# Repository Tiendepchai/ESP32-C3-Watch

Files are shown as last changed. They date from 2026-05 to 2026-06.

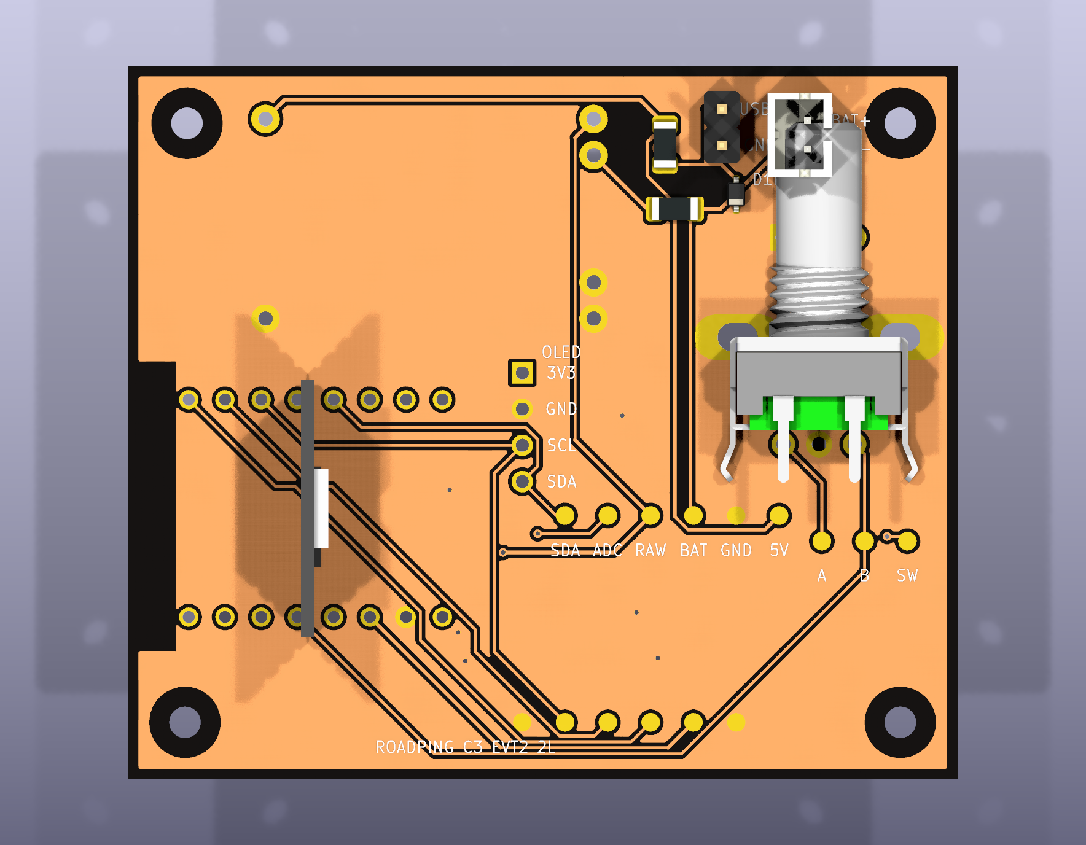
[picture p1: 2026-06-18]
hardware/kicad/roadping-c3-compact-evt-v2/analysis/baseline-top.png

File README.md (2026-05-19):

# ESP32-C3 ANCS Watch






**ESP32-C3 ANCS Watch** is an ESP-IDF firmware project for a compact BLE watch-style accessory.  
It pairs with an iPhone, subscribes to Apple Notification Center Service (ANCS), fetches notification attributes, synchronizes time, and renders notifications on a 128 × 64 SH1106 OLED display.

> **Project status:** Active firmware prototype. The core BLE/ANCS/display flow is implemented; power monitoring and iOS companion features are optional or under development.

---

## Table of Contents

- [Overview](#overview)
- [Key Features](#key-features)
- [System Architecture](#system-architecture)
- [Hardware](#hardware)
- [Firmware Layout](#firmware-layout)
- [Notification Ordering](#notification-ordering)
- [Getting Started](#getting-started)
- [Build and Flash](#build-and-flash)
- [Usage](#usage)
- [Testing Checklist](#testing-checklist)
- [Troubleshooting](#troubleshooting)
- [Roadmap](#roadmap)
- [License](#license)

---

## Overview

The firmware implements the standard ANCS accessory flow:

1. The ESP32-C3 advertises as a BLE peripheral.
2. The iPhone connects and creates a secure BLE bond.
3. After encryption is enabled, the ESP32-C3 switches role logically to a GATT client and discovers ANCS on the iPhone.
4. The ESP32-C3 subscribes to the ANCS Notification Source and Data Source characteristics.
5. For each notification UID, the firmware requests:
   - `AppIdentifier`
   - `Title`
   - `Message`
   - `Date`
6. Notifications are stored locally and sorted with the newest notification first.
7. The display manager renders connection status, watchface, notification detail, and navigation views.

---

## Key Features

- BLE pairing and bonding powered by NimBLE.
- Bonded reconnect flow using directed advertising first, then general advertising fallback.
- ANCS discovery, CCCD subscription, notification event handling, and attribute parsing.
- Date-based notification ordering using ANCS `Date` when available.
- Temporary local receive timestamp while waiting for notification attributes.
- iOS Current Time Service client for watchface time synchronization.
- SH1106 128 × 64 OLED rendering for:
  - connection status
  - watchface
  - notification list/detail
  - navigation state
- In-memory notification store with configurable filtering.
- NVS-backed settings and bond state persistence.
- Two-button physical control for:
  - notification navigation
  - clearing notifications
  - changing filters
  - resetting bond state
- Optional SwiftUI companion scaffold for future configuration and navigation handoff.

---

## System Architecture

```text
┌────────────────────┐
│      iPhone        │
│  ANCS + CTS Server │
└─────────┬──────────┘
          │ BLE encrypted link
          ▼
┌──────────────────────────────────────┐
│              ESP32-C3                │
│                                      │
│  ┌───────────────┐   ┌────────────┐  │
│  │ BLE Manager   │──▶│ ANCS Client│  │
│  └───────┬───────┘   └─────┬──────┘  │
│          │                 │         │
│          ▼                 ▼         │
│  ┌───────────────┐   ┌─────────────┐ │
│  │ CTS Client    │   │ Notification│ │
│  │ Time Sync     │   │ Store       │ │
│  └───────┬───────┘   └─────┬───────┘ │
│          │                 │         │
│          ▼                 ▼         │
│  ┌────────────────────────────────┐  │
│  │        Display Manager         │  │
│  │      SH1106 OLED Rendering     │  │
│  └────────────────────────────────┘  │
│                                      │
│  ┌────────────────────────────────┐  │
│  │        Storage Manager         │  │
│  │        NVS Settings/Bonds      │  │
│  └────────────────────────────────┘  │
└──────────────────────────────────────┘
```

---

## Hardware

| Component | Specification |
| --- | --- |
| MCU | ESP32-C3 |
| Display | SH1106 128 × 64 OLED |
| Display bus | I2C |
| Button A | GPIO3, active low |
| Button B | GPIO4, active low |

### Default Wiring

| Function | ESP32-C3 Pin |
| --- | --- |
| OLED VCC | 3V3 |
| OLED GND | GND |
| OLED SDA | GPIO6 |
| OLED SCL | GPIO7 |
| Button A | GPIO3 to GND |
| Button B | GPIO4 to GND |

Board-level constants are defined in:

```text
components/board_config/include/board_config.h
```

---

## Firmware Layout

| Path | Purpose |
| --- | --- |
| `main/` | Application state machine, UI flow, and event orchestration |
| `components/ble_manager/` | NimBLE initialization, advertising, bonding, reconnect, and config GATT service |
| `components/ancs_client/` | ANCS discovery, notification subscription, attribute request, and response parser |
| `components/cts_client/` | iOS Current Time Service client |
| `components/display_manager/` | SH1106 driver, framebuffer, watchface rendering, and notification rendering |
| `components/notification_store/` | In-memory notification storage, filtering, and sorting |
| `components/storage_manager/` | NVS-backed settings and persistent state |
| `components/power_manager/` | Optional battery and power monitoring |
| `ios/ANCSWatchConfig/` | Optional SwiftUI companion app scaffold |

---

## Notification Ordering

The notification ordering pipeline is designed to avoid relying only on local receive time.

```text
ANCS Notification Source event
        │
        ▼
Extract NotificationUID
        │
        ▼
Request attributes:
AppIdentifier, Title, Message, Date
        │
        ▼
Parse ANCS Data Source response
        │
        ▼
Use ANCS Date if available
        │
        ▼
Update notification record
        │
        ▼
Sort newest first
```

When a notification event first arrives, the firmware stores it with the local receive timestamp as a temporary value.  
After the ANCS `Date` attribute is fetched, the stored record is updated and the notification list is re-sorted by timestamp in descending order.

This allows notifications such as:

```text
Messenger  - 1 second ago
MoMo       - 2 minutes ago
```

to appear in the expected order, with the newest notification at the top.

---

## Getting Started

### Prerequisites

Install and configure:

- ESP-IDF v6.0 or newer
- Python environment required by ESP-IDF
- USB serial driver for your ESP32-C3 board
- An iPhone with Bluetooth enabled
- Optional: nRF Connect for BLE debugging

### Clone the Repository

```bash
git clone <your-repository-url>
cd esp32-c3-ancs-watch
```

### Set the ESP-IDF Target

```bash
idf.py set-target esp32c3
```

---

## Build and Flash

### Activate ESP-IDF

Use the activation script generated by your ESP-IDF installation.

Example:

```bash
source "$HOME/.espressif/tools/activate_idf_v6.0.sh"
```

Alternatively, if ESP-IDF is installed globally:

```bash
. "$IDF_PATH/export.sh"
```

### Build

```bash
idf.py build
```

### Flash

Replace the port with the serial device used by your board.

```bash
idf.py -p /dev/cu.usbmodemXXXX flash
```

### Monitor Logs

```bash
idf.py -p /dev/cu.usbmodemXXXX monitor
```

### Flash and Monitor in One Command

```bash
idf.py -p /dev/cu.usbmodemXXXX flash monitor
```

---

## Usage

### First Pairing

1. Flash the firmware to the ESP32-C3.
2. Open the Bluetooth settings on iOS.
3. Select the ESP32-C3 accessory.
4. Accept the pairing request.
5. Wait until the BLE link is encrypted and ANCS discovery completes.
6. Send a test notification to the iPhone.
7. Verify that the OLED displays the notification.

### Reconnect Flow

After a successful bond, the firmware tries:

1. Directed advertising to the bonded iPhone.
2. General advertising fallback if directed reconnect fails.
3. ANCS rediscovery after the encrypted link is restored.

### Button Controls

| Action | Expected Behavior |
| --- | --- |
| Button A | Navigate through notifications or UI views |
| Button B | Change filter, clear notification, or trigger secondary action |
| Long press / configured combo | Reset bond state or enter maintenance flow |

> Exact button behavior depends on the current firmware state machine and board configuration.

---

## Testing Checklist

Before testing a first-pair flow:

- Clear the iOS Bluetooth bond for the ESP32-C3.
- Clear stored bonds on the ESP32-C3.
- Reboot both devices if bonding behavior is inconsistent.

Recommended validation sequence:

- Pair from iOS or nRF Connect.
- Confirm the first bond is retained locally.
- Check logs for:

```text
bond store peers after secure=1
```

- Wait for:

```text
ANCS ready, attrs=enabled
```

- Send several notifications from different apps.
- Verify that notification details are fetched correctly.
- Verify that notifications are sorted by ANCS `Date`.
- Walk out of range to force a disconnect.
- Return to range and confirm bonded reconnect works.
- Confirm pre-existing or pending notifications can wake the display and render correctly.
- Test button navigation, filter changes, clear action, and bond reset.

---

## Troubleshooting

### ANCS does not become ready

Check that:

- The iPhone accepted the BLE pairing request.
- The connection is encrypted.
- The ESP32-C3 bond was not erased after pairing.
- ANCS discovery runs only after encryption.
- Notification permissions are enabled on iOS.

Useful log marker:

```text
ANCS ready, attrs=enabled
```

### Notifications appear but details are missing

Check that:

- Data Source subscription succeeded.
- Control Point writes are accepted.
- `GetNotificationAttributes` is sent with the correct `NotificationUID`.
- The parser handles fragmented Data Source responses.

### Notification order is incorrect

Check that:

- `Date` is included in the requested ANCS attributes.
- The firmware updates the temporary receive timestamp after `Date` arrives.
- The notification store re-sorts the list after attribute parsing.

### Reconnect does not work

Check that:

- Bond data is stored in NVS.
- Directed advertising uses the bonded peer address.
- General advertising fallback starts after directed advertising fails.
- iOS still has the accessory saved in Bluetooth settings.

### macOS ESP-IDF `platform.mac_ver()` issue

If the local Python environment fails because of a macOS version parsing issue, use a clean ESP-IDF Python environment first.  
If the issue persists, the following development workaround can be used:

```bash
IDF_COMPONENT_MANAGER=0 python -c 'import os, platform, runpy, sys; tools=os.path.join(os.environ["IDF_PATH"],"tools"); sys.path.insert(0,tools); platform.mac_ver=lambda release="", versioninfo=("", "", ""), machine="": ("26.1", ("", "", ""), os.uname().machine); sys.argv=[os.path.join(tools,"idf.py")]+sys.argv[1:]; runpy.run_path(sys.argv[0], run_name="__main__")' build
```

---

## Roadmap

- [ ] Add battery percentage monitoring.
- [ ] Add charging status display.
- [ ] Improve notification grouping by app.
- [ ] Add persistent notification history if required.
- [ ] Finalize iOS SwiftUI companion app.
- [ ] Add configurable button actions.
- [ ] Add screenshots or hardware photos.
- [ ] Add CI build workflow for ESP-IDF.
- [ ] Add release binaries and flashing instructions.

---

## License

This project is licensed under the MIT License. See [LICENSE](LICENSE) for details.

---

## Vietnamese Summary

**ESP32-C3 ANCS Watch** là firmware ESP-IDF cho thiết bị đeo nhỏ dùng BLE. Thiết bị ghép đôi với iPhone, subscribe Apple Notification Center Service, lấy thông tin `AppIdentifier`, `Title`, `Message`, `Date`, sau đó hiển thị thông báo lên OLED SH1106 128 × 64.

Điểm chính:

- Pairing/bonding BLE bằng NimBLE.
- Tự reconnect với iPhone đã bond.
- Fetch chi tiết thông báo qua ANCS.
- Sort thông báo theo `Date` để thông báo mới nhất hiện trên đầu.
- Đồng bộ giờ qua iOS Current Time Service.
- Hiển thị watchface và notification bằng SH1106 OLED.
- Lưu cấu hình bằng NVS.
- Điều khiển bằng hai nút vật lý.

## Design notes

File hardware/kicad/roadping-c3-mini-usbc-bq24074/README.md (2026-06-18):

# RoadPing C3 Mini - USB-C + BQ24074

Production-oriented KiCad design for a compact ESP32-C3 board.

## Key Components

- **ESP32-C3-MINI-1-N4** — RISC-V Wi-Fi/BLE SoC module
- **BQ24074** — Linear battery charger with power-path management
- **Single USB-C port** — Charge battery + flash firmware
- **SH1106 OLED** — Connected via I2C on GPIO 0/1 (or alternative)

## Design Directives

- Power path: USB-C 5V -> BQ24074 -> 3.3V LDO -> ESP32-C3 + peripherals
- LiPo/Li-ion battery management with NTC thermistor monitoring
- Single USB-C for both charging and UART/JTAG flashing
- Compact form factor (< 50 x 25 mm)

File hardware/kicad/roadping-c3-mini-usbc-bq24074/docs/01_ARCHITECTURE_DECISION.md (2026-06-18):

# Architecture Decision Record: RoadPing C3 Mini

**Date:** 2026-06-16
**Board:** RoadPing C3 Mini (roadping-c3-mini-usbc-bq24074)
**Status:** DRAFT (pre-schematic)

---

## 1. Overview

RoadPing C3 Mini is a compact iOS ANCS notification display with SH1106 OLED, PEC11R encoder, and LiPo battery power. This document records the five highest-impact architecture decisions.

### Design Goals (ranked)
- P0: Single USB-C port for charge + flash/debug
- P0: Charge-and-run (power-path) on 1S LiPo
- P0: Native USB-SERIAL-JTAG (no external UART bridge)
- P1: Board area < 4000 mm² (80×50 mm target)
- P1: BLE ANCS push notification display
- P2: Battery voltage monitoring

## 2. Decision 1: MCU Selection — ESP32-C3-MINI-1-N4

| Parameter | ESP32-C3-MINI-1-N4 | ESP32-S3-MINI-1-N8 | ESP32-PICO-V3-ZERO |
|---|---|---|---|
| Core | Single RISC-V 160 MHz | Dual Xtensa LX7 240 MHz | Dual Xtensa LX6 240 MHz |
| Native USB | USB-SERIAL-JTAG | USB OTG | USB OTG |
| BLE | BLE 5.0 | BLE 5.0 | Classic BT + BLE 4.2 |
| Flash/PSRAM | 4MB / none | 8MB / 2MB | 4MB / 2MB |
| Module area | 18.0×22.5 mm | 18.0×25.5 mm | 21.0×21.0 mm |
| GPIO available | 14 | 26 | 27 |
| Price (1k) | ~$2.50-3.00 | ~$3.50-4.50 | ~$4.00-5.00 |

**Rationale:** Native USB-SERIAL-JTAG eliminates external UART bridge. Sufficient compute for ANCS + display. Smallest footprint. Adequate GPIO count (12 used of 14). Lower power than S3/PICO.

## 3. Decision 2: Power-Path Charger — BQ24074RGTR

Replaces TP4056 module. True power-path management (DPPM):
- USB present → system powered from USB, battery charged
- USB removed → seamless switch to battery (<20µs)
- No discrete ORing diodes or P-MOSFET required

| Feature | TP4056 (EVT) | BQ24074 (This design) |
|---|---|---|
| Power path | None | True DPPM |
| Package | THT module | WQFN-20 (3.5×3.5 mm) |
| PCB area | ~600 mm² | ~60 mm² |
| Charge current | 1A (R_PROG) | 1.5A max (ISET) |
| Status outputs | Single CHG LED | CHG + FAULT open-drain |
| NTC monitoring | None | TS pin (JEITA) |
| Safety timer | None | 5h default |

**ISET=1.1kΩ → ~910mA charge, ILIM=10kΩ → ~500mA input limit. TS fixed 10k+10k divider (no NTC).**

### Power Tree
```
USB-C VBUS (5V) → PTC F1 (1206L110SLWR) → TVS D1 (PESD5V0S1BA)
  → BQ24074 IN → BQ24074 OUT (SYS_RAW) → AP2112K-3.3 → 3V3 rail
               → BQ24074 BAT → JST-PH LiPo
```

## 4. Decision 3: USB-C Input — TYPE-C-31-M-12

Native USB-C receptacle with CC 5.1kΩ pulldowns (sink). USBLC6-2SC6 ESD on D+/D-.

```
USB-C D+ → USBLC6-2SC6 → opt 27Ω R → GPIO19 (USB_D+)
USB-C D- → USBLC6-2SC6 → opt 27Ω R → GPIO18 (USB_D-)
```

## 5. Decision 4: Gated Battery ADC (BSS138)

470k+470k divider gated by BSS138 N-FET. Gate HIGH → divider enabled, ADC reads VBAT×0.5. Gate LOW → <1µA leakage. GPIO1 gate control.

**Phase plan:** Phase 1 = gated ADC, Phase 2 = MAX17048 fuel gauge (future).

## 6. Decision 5: 4-Layer Stackup

F.Cu / In1.Cu (GND plane) / In2.Cu (PWR) / B.Cu. 1.6mm, ENIG. USB D+/D- 90Ω differential on F.Cu ref In1.Cu.

## 7. GPIO Allocation

| GPIO | Function | GPIO | Function |
|---|---|---|---|
| 0 | BAT_ADC (ADC1_CH0) | 6 | BQ24074_CHG (input) |
| 1 | GPIO_EN_ADC (BSS138 gate) | 7 | BQ24074_FAULT (input) |
| 2 | ENC_A | 8 | I2C_SDA |
| 3 | ENC_B | 9 | BOOT (unconnected) |
| 4 | ENC_SW | 10 | I2C_SCL |
| 5 | BQ24074_CE (output) | 18 | USB_D- | 19 | USB_D+ | 20 | UART_RX | 21 | UART_TX |

Total: 15 GPIOs used.

## 8. Schematic Fragments

### USB-C Input
```
J1: A1/A12/B1/B12=GND, A4/A9/B4/B9=VBUS, A5=CC1→5.1k→GND, B5=CC2→5.1k→GND
A6/B6=D+→USBLC6→GPIO19, A7/B7=D-→USBLC6→GPIO18
Shield: 1MΩ + 0.1µF to GND
```

### BQ24074
```
U1: IN(1,2)=VBUS, OUT(8)=SYS_RAW, BAT(12,13)=BAT_CONN+
ISET(4)=1.1k→GND, ILIM(5)=10k→GND, TS(6)=10k→OUT + 10k→GND
/CE(7)=GPIO5↑10k, CHG(10)=GPIO6↑10k, FAULT(11)=GPIO7↑10k
```

### AP2112K
```
U2: VIN(1)=SYS_RAW, EN(3)=SYS_RAW, VOUT(5)=3V3
```

### Gated ADC
```
Q1(BSS138): GATE=GPIO1+100k→GND, DRAIN=divider jct, SOURCE=GND
R_TOP=470k VBAT→divider, R_BOTTOM=470k divider→Q1 drain
C_FILTER=100n divider→GND, divider→GPIO0
```

### SH1106
```
DS1: VDD=3V3, GND=GND, SCK=GPIO10, SDA=GPIO8
Pull-ups: 4.7k DNP
```

### PEC11R
```
S1: A=GPIO2↑10k, C=GND, B=GPIO3↑10k
SW: 1=GPIO4↑10k, 2=GND
Debounce: 10n DNP
```

### UART Debug
```
TP_TX=GPIO21, TP_RX=GPIO20, TP_GND=GND, TP_3V3=3V3
Pads: 1.3mm round, ENIG, 2.54mm pitch
```

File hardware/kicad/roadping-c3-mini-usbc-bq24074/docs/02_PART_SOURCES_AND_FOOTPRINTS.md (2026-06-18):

# Part Sources and Footprints

| Part Name | Manufacturer | Package | Datasheet Source | Symbol Source | Footprint Source | Risk | Decision | Notes |
|---|---|---|---|---|---|---|---|---|
| ESP32-C3-MINI-1-N4 | Espressif | 42-pin castellated SMD module, 15.5 x 20.0 mm, 2.0 mm pitch | <https://www.espressif.com/sites/default/files/documentation/ESP32-C3-MINI-1_Datasheet_EN.pdf> | Custom `roadping-c3:ESP32-C3_SUPERMINI_TH` (via project sym lib) **but this is a different part** — SuperMini_TH dev board, not MINI-1-N4 | Custom `roadping-c3:MODULE_ESP32-C3_SUPERMINI_TH` (via project footprint lib) **same mismatch** | MEDIUM | NEED_REVIEW | PART MISMATCH: docs name "ESP32-C3-MINI-1-N4" but schematics use SuperMini_TH symbol/footprint. Incompatible packages — 42-pin SMD vs 2.54 mm THT. Pinout, pitch, and landing pattern differ entirely. N4 variant = 4 MB flash, 400 KB SRAM, no PSRAM. Resolve module intent, then either (a) adopt MINI-1-N4 with official Espressif KiCad assets, or (b) keep SuperMini_TH and update all documentation. |
| BQ24074RGTR | Texas Instruments | WQFN-20 (3.5 x 3.5 mm, 0.5 mm pitch, EP 2.7 x 2.7 mm) | <https://www.ti.com/lit/ds/symlink/bq24074.pdf> | `Battery_Management:BQ24074_RGT` (KiCad official) | `Package_DFN_QFN:WQFN-20-1EP_3.5x3.5mm_P0.5mm_EP2.7x2.7mm` (KiCad official) | MEDIUM | NEED_REVIEW | Part not used in main compact-evt-v2 design (that uses TP4056 THT module). BQ24074 only in mini-usbc-bq24074 variant. WQFN-20 requires reflow assembly vs TP4056 hand-solderable module. Technically superior (power-path management, NTC, 1.5 A charge) but full schematic/layout review needed. Mini board is a PoC, not production-validated. |
| USBLC6-2SC6 | STMicroelectronics | SOT-23-6 | <https://www.st.com/resource/en/datasheet/usblc6-2sc6.pdf> | `Interface_Protection:USBLC6-2SC6` (KiCad official) | `Package_TO_SOT_SMD:SOT-23-6` (KiCad official) | LOW | ACCEPT | **RE-EVALUATED from REJECT.** NEW design uses ESP32-C3-MINI-1-N4 bare module with exposed D+/D- lines (GPIO19/18) requiring external ESD. USBLC6-2SC6 provides IEC 61000-4-2 ±15kV protection, 0.6pF line cap (USB 2.0 compatible). Feed-through routing: D+→pin1→GPIO19, D-→pin3→GPIO18. VBUS bias on pins 4,6. Place <5mm from USB-C receptacle. Series 27Ω resistors optional for impedance match. |
| TYPE-C-31-M-12 | Korean Hroparts Elec (HRO) | 16-pin SMT USB-C receptacle | <https://www.lcsc.com/product-detail/USB-Type-C_Korean-Hroparts-Elec-TYPE-C-31-M-12_C398303.html> (LCSC); PDF <https://datasheet.lcsc.com/lcsc/2201121930_Korean-Hroparts-Elec-TYPE-C-31-M-12_C398303.pdf> (unverified) | `Connector_USB:USB_C_Receptacle_USBIF` (KiCad official generic 16-pin) | `Connector_USB:USB_C_Receptacle_HRO_TYPE-C-31-M-12` (KiCad official) | MEDIUM | NEED_REVIEW | Onboard receptacle of the TP4056 charging module (U1), not a direct PCB part. TP4056 module SKU not locked (DVT status: BLOCKED_PENDING_VENDOR_LOCK). Critical unknowns: CC pin handling (likely passive breakout without Rp/Rd — may not negotiate power with USB-C PD sources), current rating, mechanical envelope. Design routes 5V via J1 2-pin header, bypassing module USB-C. Lock exact TP4056 SKU and verify connector behavior before production, or implement native USB-C with CC logic as ECO. See BOM.md, dvt_ordering_lock docs, production_closure/04_FOOTPRINT_VENDOR_VALIDATION.md. |
| AP2112K-3.3TRG1 | Diodes Incorporated | SOT-23-5 | <https://www.diodes.com/datasheet/download/AP2112.pdf> | `roadping-c3:AP2112K-3.3` (project custom sym lib `roadping-c3.kicad_sym`) | `Package_TO_SOT_SMD:SOT-23-5` (KiCad official) | LOW | ACCEPT | Mature 600 mA LDO. Dropout ~100 mV at 100 mA. Ample margin for ESP32-C3 (250 mA peak) + OLED (40 mA). EN pin available for firmware power gating. 1 uF I/O caps per datasheet. NC pin 4 correctly left unconnected. All metadata (MPN, pinout 1=VIN/2=GND/3=EN/4=NC/5=VOUT, datasheet URL) consistent and correct. |
| PEC11R-4215F-S0024 | Bourns | 12 mm rotary encoder, panel mount | <https://www.bourns.com/docs/Product-Datasheets/PEC11R.pdf> | `roadping-c3:PEC11R-4215F-S0024` (project custom sym lib `roadping-c3.kicad_sym`) | `roadping-c3:XDCR_PEC11R-4215F-S0024` (project custom footprint lib `roadping-c3.pretty`) | LOW | ACCEPT | Datasheet verified against schematic on 2026-05-30 (per DESIGN_NOTES.md). Terminals A/C/B and switch pins 1/2 confirmed matching Bourns PEC11R datasheet. 3D model at `roadping-c3.3dshapes/PEC11R-4215F-S0024.step`. A/B/SW pull-ups (10k) and DNP debounce caps placed per datasheet. Remaining items are production mechanical checks (drill size, support slots, shaft clearance) — none are EVT blockers. |
| BSS138 | onsemi | SOT-23 | <https://www.onsemi.com/pdf/datasheet/bss138-d.pdf> | `Transistor_FET:BSS138` (KiCad official) | `Package_TO_SOT_SMD:SOT-23` (KiCad official) | LOW | ACCEPT | N-ch MOSFET, 50 V / 220 mA. Vgs(th) ~0.8–1.5 V, suitable for 3.3 V logic level shifting and low-side switching. Not present in current BOM or PCB — design uses 3.3V-only I2C (ESP32-C3 + OLED), so no level-shifting needed. If I2C level translation to 5V bus is required in a future rev, BSS138 is an excellent fit. Well-characterized part, billions in production. |
| JST-PH-B2B-PH-K | JST | 2-pin, 2.0 mm pitch, vertical THT | <https://www.jst-mfg.com/product/pdf/eng/ePH.pdf> | Custom `JST_PH_2PIN_LIPO` (project lib `roadping-c3.kicad_sym`). Official equivalent: `Connector_JST:JST_PH_B2B-PH-K_1x02_P2.00mm_Vertical` | `Connector_JST:JST_PH_B2B-PH-K_1x02_P2.00mm_Vertical` (KiCad official `Connector_JST.pretty`) | MEDIUM | ACCEPT | JST PH series, 2 A/pin, -25/+85 deg C. Standard for LiPo battery connections. Key risk: no mechanical polarization on 2-pin version — battery can be plugged in reverse. Schematic flags this ("Check polarity before connecting battery"). Verify reverse-polarity protection circuitry (MOSFET or diode) downstream. 2 A rating adequate for ESP32-C3 + TP4056 1 A charging. Thread locker recommended on THT pins under vibration. |
| SH1106-OLED-4PIN | (Various, Sitronix SH1106 controller) | 4-pin THT, 2.54 mm pitch, 1.3" 128x64 OLED | <https://cdn-shop.adafruit.com/datasheets/SH1106_datasheet.pdf> | `OLED_128X64_1.3_I2C` (project custom sym lib, SnapEDA-sourced from UNIVERSAL-SOLDER Electronics Ltd, in `hardware/kicad/symbols/OLED_128X64_1.3_I2C.kicad_sym`) | `OLED_4PIN_VDD_GND_SCK_SDA_2.54MM` (project custom footprint in `roadping-c3-compact-evt-v2/roadping-c3.pretty`) | LOW | ACCEPT | Pin order verified by user as VDD-GND-SCK-SDA matching symbol. I2C address tentative 0x3C/0x3D (bring-up TBD). I2C SCL on GPIO10 (safety fix, not GPIO9). No dedicated RST pin connected. 4.7k pull-ups DNP (relies on module internals). Module dimensions provisional. Standard bring-up risk only. |
| 1206L110SLWR | Littelfuse | 1206 SMD (PTC resettable fuse) | <https://www.littelfuse.com/products/resettable-ptcs/表面贴装/1206l-series.aspx> | `Device:Fuse_PTC` (KiCad official) | `Fuse:Fuse_1206_3216Metric` (KiCad official) | LOW | ACCEPT | 1.10A hold, 2.20A trip, 6VDC max. Rmin 0.020Ω, Rmax initial 0.080Ω, Rmax post-trip 0.140Ω. 1.1A hold provides margin over 1A nominal USB load. Time to trip at 5A ~1.0s. UL/TUV/cUL approved. |
| PESD5V0S1BA | Nexperia | SOD-323 | <https://assets.nexperia.com/documents/data-sheet/PESD5V0S1BA.pdf> | `PESD5V0S1BA` in `Interface_Protection` (KiCad 7/8 official) | `Diode_SMD:D_SOD-323` (KiCad official; may be `Package_TO_SOT_SMD:SOD-323` in some versions) | LOW | ACCEPT | Bidirectional ESD diode, 5 V VRWM, SOD-323. Confirm datasheet URL resolves in your region. Verify exact KiCad footprint library name (version-dependent). |

---

## Notes

- This table was generated by research agents. Cross-check each footprint against manufacturer mechanical drawing before PCB order.
- Symbols marked as KiCad built-in may need pin name/position adjustments.
- Decisions marked NEED_REVIEW must be resolved before DVT.

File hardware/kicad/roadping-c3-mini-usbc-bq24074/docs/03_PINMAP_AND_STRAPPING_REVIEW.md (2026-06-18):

# PINMAP and Strapping Review

**Board:** RoadPing C3 Mini (ESP32-C3-MINI-1-N4)
**Project:** `roadping-c3-mini-usbc-bq24074`
**Date:** 2026-06-16

---

## 1. Complete Pin Map (ESP32-C3-MINI-1-N4)

### 1.1 Module Pins

The ESP32-C3-MINI-1-N4 is a 42-pin castellated SMD module. Pin mapping below is based on the Espressif datasheet.

**Key pin assignments for this design:**

| GPIO | Function | Net | Pull | Strapping Risk |
|---|---|-----|---|---|
| 0 | ADC1_CH0 | BAT_ADC (gated) | Divider | LOW=download mode — BSS138 gate OFF at reset = Hi-Z, safe |
| 1 | GPIO | GPIO_EN_ADC | 100k↓ GND | Not strapping — safe |
| 2 | ENC_A | ENC_A | 10k↑ 3V3 | HIGH needed for boot — 10k pull-up ensures HIGH |
| 3 | ENC_B | ENC_B | 10k↑ 3V3 | Not strapping |
| 4 | ENC_SW | ENC_SW | 10k↑ 3V3 | Not strapping |
| 5 | GPIO | BQ24074_CE | 10k↑ 3V3 | NOT strap on ESP32-C3 — safe |
| 6 | GPIO | BQ24074_CHG | 10k↑ 3V3 | Not strapping |
| 7 | GPIO | BQ24074_FAULT | 10k↑ 3V3 | Not strapping |
| 8 | I2C_SDA | I2C_SDA | 4.7k DNP | Samples for VDD_SPI — 10k pull-up → HIGH = 3.3V, safe |
| 9 | BOOT | BOOT_GPIO9 | Internal↑ | LOW=download — test pad, no external pulldown |
| 10 | I2C_SCL | I2C_SCL | 4.7k DNP | Not strapping |
| 18 | USB_D- | USB_DN | — | Not strapping |
| 19 | USB_D+ | USB_DP | — | Not strapping |
| 20 | UART_RX | UART_RX | — | Not strapping |
| 21 | UART_TX | UART_TX | — | Not strapping |

### 1.2 Peripheral Connections

| Peripheral | Pin | Net | GPIO |
|---|-----|-----|---|
| SH1106 OLED | VDD | 3V3 | — |
| SH1106 OLED | GND | GND | — |
| SH1106 OLED | SCK | I2C_SCL | GPIO10 |
| SH1106 OLED | SDA | I2C_SDA | GPIO8 |
| PEC11R A | A | ENC_A | GPIO2 |
| PEC11R B | B | ENC_B | GPIO3 |
| PEC11R SW | SW1 | ENC_SW | GPIO4 |
| PEC11R COM | C | GND | — |
| JST-PH + | 1 | BAT_CONN+ | — |
| JST-PH - | 2 | GND | — |
| BQ24074 CE | 7 | GPIO5 | — |
| BQ24074 CHG | 10 | GPIO6 | — |
| BQ24074 FAULT | 11 | GPIO7 | — |
| BSS138 gate | GATE | GPIO1 | — |

### 1.3 Charger Status GPIOs

| GPIO | Net | Pull | Meaning |
|---|-----|---|---|
| GPIO5 | CE_CHG_EN | 10k↑ 3V3 | Charger enable (active low) |
| GPIO6 | CHG_STATUS | 10k↑ 3V3 | Charging indicator (active low) |
| GPIO7 | FLT_STATUS | 10k↑ 3V3 | Fault indicator (active low) |

### 1.4 Test Pads

| Pad | Net | GPIO |
|-----|-----|---|
| TP_GND | GND | — |
| TP_3V3 | 3V3 | — |
| TP_TX | UART_TX | GPIO21 |
| TP_RX | UART_RX | GPIO20 |
| TP_SCL | I2C_SCL | GPIO10 |
| TP_BOOT | BOOT_GPIO9 | GPIO9 |

Pads: 1.3mm round, exposed copper, ENIG, 2.54mm pitch.

---

## 2. Old vs New Pin Map

| Function | Old (Super Mini) | New (MINI-1-N4) |
|---|---|---|
| I2C_SDA | GPIO8 | GPIO8 |
| I2C_SCL | GPIO10 | GPIO10 |
| UART_TX | GPIO21 | GPIO21 |
| UART_RX | GPIO20 | GPIO20 |
| ENC_A | GPIO2 | GPIO2 |
| ENC_B | GPIO3 | GPIO3 |
| ENC_SW | GPIO4 | GPIO4 |
| BAT_ADC | GPIO0 | GPIO0 (gated) |
| BOOT | GPIO9 | GPIO9 (pull-up) |
| USB_D+ | N/A | GPIO19 |
| USB_D- | N/A | GPIO18 |
| CHG status | N/A | GPIO6 |
| FAULT status | N/A | GPIO7 |
| CE control | N/A | GPIO5 |
| BAT_GATE | N/A | GPIO1 |

---

## 3. Strapping Pin Analysis (ESP32-C3)

| GPIO | Function | Pull at Reset | Required State | Conflict? |
|:----:|---|:---:|---|:---:|
| 0 | BAT_ADC (gated) | BSS138 OFF = Hi-Z | HIGH for normal boot | No — FET isolated at reset |
| 2 | ENC_A (10k↑ 3V3) | 3.3V | HIGH for normal boot | No — pull-up ensures HIGH |
| 5 | CE_CHG_EN (10k↑ 3V3) | 3.3V | HIGH for 3.3V SPI | No — not strap on C3 |
| 8 | I2C_SDA (pull-up) | HIGH via pull-up | HIGH (suppress ROM log) | No — SDA undriven at reset |
| 9 | Unconnected (TP only) | Internal pull-up ~10k | HIGH for normal boot | **No conflict** — safety fix applied |

**Summary: No strapping conflicts remain.**

---

## 4. Risks and Bring-Up Checks

| Risk | Impact | Mitigation |
|---|---|---|
| GPIO0 divider voltage near V_IH at deep discharge | Could enter indeterminate strapping state | BSS138 gate OFF at reset = Hi-Z, isolated |
| GPIO2 toggles during reset (encoder rotation) | Strapping state captured incorrectly | 10k pull-up dominates encoder low |
| I2C bus contention during ESP32 reset | SDA/SCL held by OLED slave | I2C slaves release bus on power loss |

**Bring-up sequence:**
1. Power from USB, no LiPo, OLED disconnected
2. Measure VBAT (floating), SYS_RAW (~4.4V), 3V3 (3.3V±2%)
3. Verify GPIO0 >0.8V, GPIO9 ~3.3V
4. Connect OLED, verify I2C scan finds 0x3C/0x3D
5. Confirm normal boot and download mode entry via TP15

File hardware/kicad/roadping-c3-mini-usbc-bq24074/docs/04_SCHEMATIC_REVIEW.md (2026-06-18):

# Schematic Review — RoadPing C3 Mini

**Date:** 2026-06-16
**Status:** Pre-schematic design review

---

## 1. Scope

Schematic block design for RoadPing C3 Mini with ESP32-C3-MINI-1-N4 + BQ24074 + USB-C.

| # | Block | Key Components |
|---|---|---|
| 1 | USB-C Input | TYPE-C-31-M-12, PTC, TVS, USBLC6-2SC6 |
| 2 | Battery Charger | BQ24074RGTR, ISET/ILIM/TS resistors |
| 3 | 3.3V Regulation | AP2112K-3.3 |
| 4 | MCU | ESP32-C3-MINI-1-N4 |
| 5 | I2C Bus | SH1106 OLED, pull-ups |
| 6 | Rotary Encoder | PEC11R-4215F-S0024 |
| 7 | Battery ADC | BSS138 gated divider, 470k+470k |
| 8 | Charger Status | CE(GPIO5), CHG(GPIO6), FAULT(GPIO7) |
| 9 | UART Debug | GPIO20/21, test pads |
| 10 | Protection | PTC, TVS, decoupling |

## 2. USB-C Input

**TYPE-C-31-M-12** connections:
- VBUS: A4/A9/B4/B9 → F1(PTC) → D1(TVS) → BQ24074 IN
- CC1(A5): 5.1kΩ to GND, CC2(B5): 5.1kΩ to GND
- D+(A6/B6): → USBLC6-2SC6(pin1) → GPIO19
- D-(A7/B7): → USBLC6-2SC6(pin3) → GPIO18
- Shield: 1MΩ + 0.1µF to GND
- SBU1(A8)/SBU2(B8): NC

**Protection:** F1(1206L110SLWR, 1.1A hold), D1(PESD5V0S1BA SOD-323 TVS)

**ESD:** USBLC6-2SC6 SOT-23-6 — line cap 0.6pF, ±15kV contact. VBUS bias on pins 4,6.

## 3. BQ24074RGTR Charger

| Pin | Name | Connection |
|-----|---|---|
| 1,2 | IN | VBUS (from F1/D1) |
| 3 | VSS | GND |
| 4 | ISET | 1.1kΩ to GND (~910mA charge) |
| 5 | ILIM | 10kΩ to GND (~500mA input limit) |
| 6 | TS | 10kΩ→OUT + 10kΩ→GND (fixed) |
| 7 | /CE | GPIO5 (10k↑ 3V3) |
| 8,12 | OUT | SYS_RAW |
| 9 | PG | NC |
| 10 | /CHG | GPIO6 (10k↑ 3V3) |
| 11 | /FAULT | GPIO7 (10k↑ 3V3) |
| 13,16 | IN | VBUS |
| 14,15 | NC | NC |
| EP | GND | Thermal pad, must solder to GND |

**Passives:** C_IN=10µF+0.1µF, C_OUT=10µF+0.1µF, C_BAT=1µF

**Note:** ILIM=10kΩ gives ~100mA input limit — **needs recalculation to 1-2kΩ for 500mA-1A.**

## 4. AP2112K-3.3 LDO

| Pin | Name | Net |
|-----|---|-----|
| 1 | VIN | SYS_RAW |
| 2 | GND | GND |
| 3 | EN | SYS_RAW (always on) |
| 4 | NC | NC |
| 5 | VOUT | 3V3 |

C_IN=1µF, C_OUT=1µF, bulk 10µF on 3V3, 100nF local decoupling.

**Margin:** 600mA rated, ~290mA peak load. Dropout ~100mV@100mA.

## 5. ESP32-C3-MINI-1-N4

Key connections per pin map (Section 4 of this doc). Native USB-SERIAL-JTAG on GPIO18(D-)/GPIO19(D+).

**Boot strap pins verified safe:** GPIO0 (FET isolated), GPIO2 (10k↑), GPIO8 (pull-up), GPIO9 (unconnected).

## 6. SH1106 OLED (I2C)

VDD=3V3, GND=GND, SCK=GPIO10, SDA=GPIO8. Pull-ups 4.7k DNP.

## 7. PEC11R Encoder

A=GPIO2↑10k, C=GND, B=GPIO3↑10k, SW1=GPIO4↑10k, SW2=GND. Debounce 10n DNP.

## 8. Gated Battery ADC

BSS138: GATE=GPIO1+100k↓GND, DRAIN=divider jct, SOURCE=GND.
R_TOP=470k VBAT→divider, R_BOTTOM=470k divider→drain.
C_FILTER=100n divider→GND. Divider jct→GPIO0.

Ratio=0.5. V_ADC = VBAT×0.5 (max 2.1V at 4.2V VBAT).

**Gate pulldown required:** 100kΩ from BSS138 gate to GND ensures FET off at reset.

## 9. Design Issues

| ID | Severity | Issue | Fix |
|----|---|---|-----|
| SR-01 | HIGH | ILIM=10kΩ → ~100mA input limit | Change to 1-2kΩ |
| SR-02 | HIGH | No BSS138 gate pulldown | Add 100kΩ gate→GND |
| SR-03 | MED | PESD5V0S1BA clamp (9.8V) exceeds BQ24074 abs max (6.5V) | Accept as ESD-only; BQ24074 has internal OVP |
| SR-04 | MED | Verify MINI-1 pin mapping vs actual datasheet | Confirm before schematic entry |

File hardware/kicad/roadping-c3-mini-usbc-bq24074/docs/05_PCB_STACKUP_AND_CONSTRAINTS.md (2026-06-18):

# PCB Stackup and Constraints — RoadPing C3 Mini

**Date:** 2026-06-16
**Board:** 4-layer, ENIG, 1.6mm

---

## 1. Layer Stackup

| Layer | Name | Type | Thickness | Copper | Function |
|---|---|---|---|---|---|
| — | Top Solder Mask | Mask | 0.010mm | — | Green LPI |
| 1 | F.Cu | Signal | 0.035mm | 1oz | Components, signals, USB diff pair |
| — | Prepreg | FR4 εr=4.5 | 0.180mm | — | Dielectric |
| 2 | In1.Cu | Plane | 0.035mm | 1oz | **Continuous GND plane** |
| — | Core | FR4 εr=4.5 | 1.080mm | — | Substrate |
| 3 | In2.Cu | Plane | 0.035mm | 1oz | Power distribution (SYS_RAW plane) |
| — | Prepreg | FR4 εr=4.5 | 0.180mm | — | Dielectric |
| 4 | B.Cu | Signal | 0.035mm | 1oz | Signals, GND pour, test pads |
| — | Bottom Solder Mask | Mask | 0.010mm | — | Green LPI |

**Total:** 1.60mm. Symmetrical stackup prevents warp.

## 2. Board Dimensions

| Parameter | Value |
|---|---|
| Width | ~80mm |
| Height | ~50mm |
| Thickness | 1.6mm |
| Layers | 4 |
| Finish | ENIG |
| Copper | 1oz all layers |

## 3. Via Spec

| Parameter | Value |
|---|---|
| Type | Through-hole only |
| Pad dia | 0.6mm |
| Drill | 0.3mm |
| Annular ring | 0.15mm |
| Tenting | Both sides |

## 4. Net Classes

| Net | Width | Class |
|-----|---|---|
| VBUS | 0.5mm | POWER_HIGH |
| SYS_RAW | 0.5mm | POWER_HIGH |
| BAT+ | 0.5mm | BATTERY_CHARGE |
| VBAT | 0.5mm | BATTERY_CHARGE |
| 3V3 | 0.4mm | POWER_3V3 |
| GND | 0.4mm | GND |
| USB_D+ / USB_D- | 0.3mm | USB_DIFF (90Ω diff) |
| I2C_SCL/SDA | 0.25mm | I2C |
| UART | 0.25mm | UART_DEBUG |
| Encoder | 0.25mm | SIGNAL |
| BAT_ADC | 0.25mm | ADC_ANALOG |

## 5. USB D+/D- Differential Pair

| Parameter | Value |
|---|---|
| Target Zdiff | 90Ω |
| Model | Edge-coupled microstrip on F.Cu over In1.Cu |
| Trace width | 0.3mm |
| Trace spacing | 0.15mm |
| Length match | <2mm |
| Max length | <50mm |
| No vias on pair | F.Cu only |

## 6. Antenna Keepout

- ≥15mm clearance from module antenna edge
- No copper on any layer in keepout zone
- DRC keepout rule on all layers

## 7. BQ24074 Thermal Pad

- WQFN-20 exposed pad (2.7×2.7mm)
- ≥4×0.3mm thermal vias
- 300mm² GND copper on inner layer

## 8. Module GND Stitching

- ≥8 GND stitching vias around module perimeter
- Direct connection to In1.Cu GND plane

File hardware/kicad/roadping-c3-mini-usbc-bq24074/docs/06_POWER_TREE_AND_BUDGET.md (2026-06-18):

# Power Tree and Budget — RoadPing C3 Mini

**Date:** 2026-06-16

---

## 1. Power Tree

```
USB-C VBUS (5V)
  → PTC F1 (1206L110SLWR, 1.1A)
  → TVS D1 (PESD5V0S1BA)
  → BQ24074 IN
     |-- BQ24074 BAT → JST-PH LiPo (2000mAh)
     |-- BQ24074 OUT → SYS_RAW
                        → AP2112K-3.3 VIN/EN
                           → 3V3 rail (ESP32-C3, OLED, pull-ups)
```

## 2. Power Path Cases

1. **USB only, no battery** → BQ OUT from VBUS
2. **Battery only, no USB** → BQ OUT from BAT (8µA Iq sleep)
3. **USB + charging** → BQ OUT power-path, 910mA CC/CV
4. **USB + battery full** → BQ OUT power-path, done maintain
5. **USB removed suddenly** → BQ switches to BAT <20µs
6. **Battery low <3.0V** → Trickle charge 10%

## 3. Voltage Rails

| Rail | Source | Voltage | Notes |
|---|---|---|---|
| VBUS | USB-C | 5V ±5% | After PTC/TVS |
| SYS_RAW | BQ24074 OUT | 3.5-5.0V | USB=~4.4V, BAT=3.0-4.2V |
| VBAT | LiPo | 3.0-4.2V | 3.7V nominal, 2000mAh |
| 3V3 | AP2112K-3.3 | 3.3V ±1.5% | 600mA rated |

## 4. Power Budget

### Active (BLE on, display on)
| Component | Current |
|---|---|
| ESP32-C3 BLE active | 80mA |
| SH1106 OLED (50% pixels) | 20mA |
| Encoder pull-ups (3×10k) | 0.3mA |
| Charger status pull-ups (3×10k) | 0.3mA |
| **Total 3V3** | **~101mA** |
| LDO loss (89% eff @3.7V→3.3V) | ~13mA |
| **Total from SYS_RAW** | **~114mA** |

### Idle (BLE connected, display off)
| Component | Current |
|---|---|
| ESP32-C3 modem-sleep | 5mA |
| SH1106 OLED sleep | 1µA |
| Encoder pull-ups | 0.3mA |
| **Total 3V3** | **~5.3mA** |

### Deep Sleep
| Component | Current |
|---|---|
| ESP32-C3 deep sleep | 5µA |
| SH1106 OLED off | 1µA |
| AP2112K Iq | 55µA |
| BQ24074 Iq (battery save) | 8µA |
| Gated ADC (off) | <1µA |
| **Total from battery** | **~70µA** |

## 5. Runtime (2000mAh LiPo)

| Mode | Current | Runtime |
|---|---|---|
| Deep sleep | 70µA | ~2.9 years (theoretical) |
| Idle (BLE adv) | 0.5mA | ~166 days |
| Normal use | 50mA | ~40 hours |
| Active (continuous) | 150mA | ~13 hours |

## 6. BQ24074 Config

| Pin | Resistor | Value | Effect |
|-----|---|---|---|
| ISET | R_ISET | 1.1kΩ | ~910mA charge |
| ILIM | R_ILIM | 10kΩ | ~500mA input limit |
| TS | R_TS1+R_TS2 | 10k+10k | Fixed mid-rail (no NTC) |

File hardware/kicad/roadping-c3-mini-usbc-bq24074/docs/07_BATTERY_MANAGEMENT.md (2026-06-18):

# Battery Management

**Date:** 2026-06-16

---

## 1. BQ24074 Configuration

| Parameter | Value | Notes |
|---|---|---|
| Charge current | ~910mA | ISET=1.1kΩ |
| Input current limit | ~500mA | ILIM=10kΩ |
| TS | 10k+10k fixed | No NTC (Phase 1) |
| Pre-charge | 10% of I_CHG | V_BAT < 3.0V |
| Termination | C/10 | When I_CHG drops |
| Safety timer | 5h (default) | TMR floating |

## 2. Charger Status

| /CHG (GPIO6) | /FAULT (GPIO7) | Meaning |
|---|---|---|
| Low | High | Charging |
| High | High | Done / disabled |
| Low | Low | Battery absent / temp fault |
| High | Low | Fault condition |

Both open-drain, 10kΩ pull-ups to 3.3V.

## 3. Gated ADC Circuit

```
VBAT → 470k R_TOP → +→ GPIO0 (BAT_ADC)
                     |
                   470k R_BOTTOM
                     |
                   DRAIN (BSS138)
                   GATE  ← GPIO1 (+100k↓ GND)
                   SOURCE → GND
                   
                     +→ 100n C_FILTER → GND
```

**Operation:** GPIO1 HIGH → BSS138 ON → divider enabled → ADC reads VBAT×0.5.
GPIO1 LOW → BSS138 OFF → <1µA leakage.

**Timing:** Gate HIGH → 500ms settling → ADC read (8-16 avg) → Gate LOW.
Sampling every 30-60s.

## 4. ADC Mapping

| VBAT | V_ADC (ratio 0.5) | ADC 12-bit (11dB atten) |
|---|---|---|
| 4.2V | 2.10V | ~2608 |
| 3.7V | 1.85V | ~2296 |
| 3.3V | 1.65V | ~2048 |
| 3.0V | 1.50V | ~1862 |

ADC range with 11dB attenuation: 0-2450mV. All values within linear range.

## 5. Component Values

| Component | Value | Notes |
|---|---|---|
| R_TOP | 470kΩ 1% 0603 | VBAT to divider |
| R_BOTTOM | 470kΩ 1% 0603 | Divider to FET drain |
| C_FILTER | 100nF X7R 0603 | ADC filter |
| Q1 | BSS138 SOT-23 | Vgs(th) 0.8-1.5V |
| R_GATE_PD | 100kΩ 0603 | Gate pulldown (failsafe) |

## 6. Phase Plan

| Phase | Feature | Status |
|---|---|---|
| 1 | BQ24074 + gated ADC | **This design** |
| 2 | MAX17048 fuel gauge | Future (I2C, share bus) |

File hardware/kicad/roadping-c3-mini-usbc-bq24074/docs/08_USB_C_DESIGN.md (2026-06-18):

# USB-C Design — RoadPing C3 Mini

**Date:** 2026-06-16

---

## 1. Connector: TYPE-C-31-M-12

16-pin SMT USB-C receptacle. Mid-mount, board-edge.

| Pin | Net | Connection |
|-----|-----|---|
| A1,B1,A12,B12 | GND | GND plane |
| A4,A9,B4,B9 | VBUS | F1 PTC → BQ24074 IN |
| A5 | CC1 | 5.1kΩ to GND |
| B5 | CC2 | 5.1kΩ to GND |
| A6,B6 | D+ | USBLC6-2SC6 → GPIO19 |
| A7,B7 | D- | USBLC6-2SC6 → GPIO18 |
| A8 | SBU1 | NC |
| B8 | SBU2 | NC |
| Shield | GND | RC (1M + 0.1µF) to GND |

## 2. CC Termination

Both CC1 and CC2: 5.1kΩ ±1% to GND. Identifies device as sink (UFP).
- USB 2.0 default: 500mA
- USB-C 1.5A: up to 1.5A (with 22kΩ Rp source)
- USB-C 3.0A: up to 3A (with 10kΩ Rp source)

No PD controller needed for this current range.

## 3. VBUS Protection

| Component | Function | Spec |
|---|---|---|
| F1 — 1206L110SLWR | PTC resettable fuse | 1.1A hold, 2.2A trip |
| D1 — PESD5V0S1BA | TVS ESD diode | 5V VRWM, SOD-323 |

Topology: VBUS → D1 TVS → F1 PTC → BQ24074 IN

## 4. USB Data ESD: USBLC6-2SC6

| Parameter | Value |
|---|---|
| Package | SOT-23-6 |
| Line cap | 0.6pF |
| ESD rating | ±15kV contact |
| VBUS bias | Pins 4,6 (required for clamp) |

**Routing:** USB-C D+ → USBLC6 pin1 → GPIO19. USB-C D- → USBLC6 pin3 → GPIO18.
Pins 2,5 → GND with individual vias.

**Series resistors:** 27Ω optional between USBLC6 and ESP32-C3 for impedance matching.

## 5. Differential Pair

90Ω differential microstrip on F.Cu, referenced to In1.Cu GND.

| Parameter | Value |
|---|---|
| Trace width | 0.3mm |
| Trace spacing | 0.15mm |
| Dielectric height | 0.18mm |
| Length match | <2mm |
| Total length | <50mm |
| No vias | F.Cu only |

## 6. Layout Rules

- USBLC6 placed <5mm from USB-C receptacle
- Each GND pin (2,5) has dedicated via to GND plane
- No GND plane splits under diff pair
- ≥0.54mm clearance from other copper
- 45° chamfers, no 90° corners

## 7. BOM (USB-C Section)

| Ref | MPN | Function |
|-----|-----|---|
| J1 | TYPE-C-31-M-12 | USB-C receptacle |
| R_CC1, R_CC2 | 5.1kΩ 1% 0603 | CC pulldowns |
| F1 | 1206L110SLWR | VBUS PTC |
| D1 | PESD5V0S1BA | VBUS TVS |
| U_ESD | USBLC6-2SC6 | D+/D- ESD |

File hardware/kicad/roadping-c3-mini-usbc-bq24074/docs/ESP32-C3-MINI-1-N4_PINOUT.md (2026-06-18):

# ESP32-C3-MINI-1-N4 Complete 42-Pin Pinout

Source: Espressif ESP32-C3-MINI-1 Datasheet v1.0, Table 2: Pin Definitions

## Mechanical Overview

- 42 castellated pads
- Pins 1-21: left side (when viewed with antenna at top)
- Pins 22-42: right side (when viewed with antenna at top)
- Pin 1 is on the left side, nearest the antenna end
- Pin 22 is on the right side, nearest the antenna end

## Complete Pin Table

| Pin | Name | Type | Description |
|-----|---|---|---|
| 1 | VDD_SPI | power_in | Power supply for internal SPI flash (1.8V or 3.3V) |
| 2 | VDD3P3 | power_in | 3.3V power supply |
| 3 | CHIP_EN | input | Chip enable, high=on, low=off |
| 4 | GPIO2 | bidirectional | GPIO2 / ADC1_CH2 / FSPIQ |
| 5 | GPIO3 | bidirectional | GPIO3 / ADC1_CH3 |
| 6 | GPIO4 | bidirectional | GPIO4 / ADC1_CH4 |
| 7 | GPIO5 | bidirectional | GPIO5 / ADC1_CH5 |
| 8 | GPIO6 | bidirectional | GPIO6 / FSPID / MTMS |
| 9 | GPIO7 | bidirectional | GPIO7 / FSPIDO / MTDI |
| 10 | GPIO8 | bidirectional | GPIO8 / FSPICLK / MTCK |
| 11 | GPIO9 | bidirectional | GPIO9 / BOOT |
| 12 | GPIO10 | bidirectional | GPIO10 / FSPICS0 / MTDO |
| 13 | VDD3P3_RTC | power_in | RTC power supply (3.3V) |
| 14 | XTP_32K | input | 32.768 kHz crystal oscillator input |
| 15 | XTN_32K | input | 32.768 kHz crystal oscillator output |
| 16 | GPIO0 | bidirectional | GPIO0 / ADC1_CH0 |
| 17 | GPIO1 | bidirectional | GPIO1 / ADC1_CH1 |
| 18 | GPIO18 | bidirectional | GPIO18 / USB_D- |
| 19 | GPIO19 | bidirectional | GPIO19 / USB_D+ |
| 20 | GPIO20 | bidirectional | GPIO20 / TXD |
| 21 | GPIO21 | bidirectional | GPIO21 / RXD |
| 22 | NC | no_connect | Reserved, do not connect |
| 23 | NC | no_connect | Reserved, do not connect |
| 24 | NC | no_connect | Reserved, do not connect |
| 25 | GND | power_in | Ground |
| 26 | GND | power_in | Ground |
| 27 | GND | power_in | Ground |
| 28 | NC | no_connect | Reserved, do not connect |
| 29 | NC | no_connect | Reserved, do not connect |
| 30 | VDD3P3_CPU | power_in | 3.3V power supply for CPU |
| 31 | VDD3P3 | power_in | 3.3V power supply |
| 32 | VDD3P3 | power_in | 3.3V power supply |
| 33 | GPIO11 | bidirectional | GPIO11 / ADC2_CH0 |
| 34 | GPIO12 | bidirectional | GPIO12 / ADC2_CH1 |
| 35 | GPIO13 | bidirectional | GPIO13 / ADC2_CH2 |
| 36 | GPIO14 | bidirectional | GPIO14 / ADC2_CH3 |
| 37 | GPIO15 | bidirectional | GPIO15 / ADC2_CH4 |
| 38 | GPIO16 | bidirectional | GPIO16 / ADC2_CH5 |
| 39 | GPIO17 | bidirectional | GPIO17 / ADC2_CH6 |
| 40 | NC | no_connect | Reserved, do not connect |
| 41 | GND | power_in | Ground |
| 42 | GND | power_in | Ground |

## Notes

- GPIO0, GPIO2, GPIO5, GPIO8, GPIO9 are strapping pins — their state at reset determines boot mode.
- GPIO9 (BOOT) has internal pull-up. LOW at reset = download mode.
- CHIP_EN must not be left floating. For normal operation, connect to VDD3P3 via pull-up.
- VDD_SPI (pin 1) is the power supply for the internal SPI flash. Connect to 3.3V or leave as per module configuration.
- USB_D- (GPIO18) and USB_D+ (GPIO19) require series termination resistors (27 ohm recommended) when used with Native USB-SERIAL-JTAG.
- NC pins (22, 23, 24, 28, 29, 40) should be left unconnected per Espressif recommendation.

## Pin Types for JSON Output

power_in: VDD3P3, VDD3P3_RTC, VDD3P3_CPU, VDD_SPI, GND
input: CHIP_EN, XTP_32K, XTN_32K
bidirectional: GPIO0-21 (all GPIOs)
no_connect: NC pins

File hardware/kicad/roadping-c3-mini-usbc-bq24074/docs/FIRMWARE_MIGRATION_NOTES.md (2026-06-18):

# Firmware Migration Notes: Super Mini → ESP32-C3-MINI-1-N4

**Date:** 2026-06-16

---

## Key Changes Required

### 1. USB Serial/JTAG Console
- Change from UART console to USB-SERIAL-JTAG
- `CONFIG_ESP_CONSOLE_USB_SERIAL_JTAG=y` in sdkconfig
- UART GPIO20/21 retained as test pads for fallback only

### 2. Flash Size & Partition Table
- Change from 2MB to 4MB (MINI-1-N4 has 4MB flash)
- `CONFIG_ESPTOOLPY_FLASHSIZE_4MB=y`
- `CONFIG_PARTITION_TABLE_TWO_OTA=y` recommended

### 3. Battery ADC
- Change divider: 220k/100k → 470k/470k (ratio changes 0.3125 → 0.5)
- Update `BAT_ADC_DIVIDER_MULTIPLIER` from 3.2 to 2.0
- Fix R6/R7 compile-time check in `board_config.h`
- Add gated ADC bootstrap: GPIO1 gate control with BSS138

### 4. Charger Status GPIOs (new)
- Add `components/charger_bq24074/` with API:
  - `charger_init()` — init GPIO5(CE), GPIO6(CHG), GPIO7(FAULT)
  - `charger_get_state()` — returns CHARGER_SRC_USB / CHARGER_CHARGING / CHARGER_DONE / CHARGER_FAULT / CHARGER_BATTERY_ONLY
  - `charger_is_usb_present()` — check CHG/FAULT states

### 5. board_pins.h Updates
```c
#define BOARD_PIN_USB_DP         19
#define BOARD_PIN_USB_DN         18
#define BOARD_PIN_CHARGER_CE      5
#define BOARD_PIN_CHARGER_CHG     6
#define BOARD_PIN_CHARGER_FAULT   7
#define BOARD_PIN_BAT_GATE        1
```

### 6. ADC Settling Time
- Gate HIGH → 500ms settling → ADC read (8-16x avg) → Gate LOW
- Sample every 30-60s
- `adc1_config_channel_atten(ADC1_GPIO0_CHANNEL, ADC_ATTEN_DB_11)` required

### 7. Unchanged Components
- display_sh1106 — NO changes needed
- encoder — NO changes needed
- ui — NO changes needed
- notification_store — NO changes needed
- settings — NO changes needed
- ble_ancs — NO changes needed
- CMakeLists.txt — NO changes needed

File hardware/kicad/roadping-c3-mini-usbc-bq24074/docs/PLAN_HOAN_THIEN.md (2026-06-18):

# Plan hoàn thiện: RoadPing C3 Mini USB-C BQ24074

**Ngày:** 2026-06-17
**Target:** 2 tuần (17/06 → 01/07)
**Board size:** 40×40mm, 4-layer, ENIG
**Assembly:** JLCPCB assembled (SMT)
**EVT v2 dependency:** Không — chạy độc lập

---

## TỔNG QUAN

Project đang ở phase **Schematic DRAFT** — schematic đã có đủ linh kiện, kết nối cơ bản, nhưng:
- PCB skeleton có footprints đặt sai vị trí (tọa độ schematic, không phải layout thực)
- **BQ24074 đang dùng sai footprint** (VQFN-16 3×3mm thay vì WQFN-20 3.5×3.5mm)
- Nhiều component chưa nối dây đầy đủ (ERC còn violation)
- Cần layout lại hoàn toàn cho form factor 40×40mm

---

## PHASE 0: CRITICAL FIX — Ngay lập tức (0.5 ngày)

### 0.1 Sửa footprint BQ24074
**Vấn đề:** PCB đang dùng `VQFN-16-1EP_3x3mm_P0.5mm_EP1.6x1.6mm` — SAI.
**Cần:** `Package_DFN_QFN:WQFN-20-1EP_3.5x3.5mm_P0.5mm_EP2.7x2.7mm` — ĐÚNG.

Pin mapping WQFN-20:
| Pin | Tên | Net | Pin | Tên | Net |
|-----|-----|-----|-----|-----|-----|
| 1 | IN | VBUS | 11 | /FAULT | FLT_STAT |
| 2 | IN | VBUS | 12 | OUT | SYS_RAW |
| 3 | VSS | GND | 13 | BAT | VBAT |
| 4 | ISET | 1.1k→GND | 14 | BAT | VBAT |
| 5 | ILIM | 2.0k→GND | 15 | NC | — |
| 6 | TS | 10k→OUT+10k→GND | 16 | NC | — |
| 7 | /CE | CE_CHG | EP | GND | GND + thermal vias |
| 8 | OUT | SYS_RAW | 17 | PG | NC |
| 9 | PG | NC | 18 | TMR | GND (float = 5h) |
| 10 | /CHG | CHG_STAT | 19 | ITERM | GND (float = C/10) |
| | | | 20 | ISET2 | GND (float = not used) |

### 0.2 Dùng schematic generator script
`scripts/gen_sch.py` đã generate schematic đúng. Không chỉnh tay .kicad_sch.
Muốn sửa schematic → sửa `gen_sch.py` rồi chạy lại.

### 0.3 Sửa PCB skeleton
PCB hiện tại:
- Có ~4200+ lines footprint definitions đặt sai vị trí (tọa độ schematic như 55,30 cho module)
- Nhiều footprints chưa có net connection đúng
- Board outline và Edge.Cuts chưa có (trống)

**Cần:** Xóa hết footprint cũ, thay bằng PCB skeleton sạch, layout lại từ đầu.

---

## PHASE 1: 40×40mm PLACEMENT — 2 ngày

### 1.1 Board outline + Stackup
- **Kích thước:** 40.0 × 40.0mm
- **Edge.Cuts:** Rounded corners (3mm radius)
- **Mounting holes:** 4× M2 NPTH (2.2mm drill, 5.0mm copper keepout) tại 4 góc, nếu còn chỗ
- **Stackup:** F.Cu / In1.Cu(GND) / In2.Cu(PWR) / B.Cu, 1.6mm

### 1.2 Component placement — ràng buộc

Module ESP32-C3-MINI-1-N4 (15.5×20.0mm) chiếm phần lớn diện tích.
Đặt module ở center, các component khác xếp xung quanh.

**Sơ đồ placement đề xuất (40×40mm, nhìn từ trên xuống):**

```
┌──────────────────────────────────┐
│  USB-C (J1)         [cạnh dưới] │
├──────────────────────────────────┤
│  USBLC6          BQ24074    C    │
│  (D2)            (U1)      cap  │
│  PESD5V0S1BA     AP2112K        │
│  (D1)            (U2)           │
├──────────────────────────────────┤
│      ESP32-C3-MINI-1-N4 (U3)    │
│      15.5×20.0mm                │
│         ┌───────┐               │
│         │       │               │
│         │       │               │
│         └───────┘               │
├──────────────────────────────────┤
│  JST-PH  OLED     BOOT  Debug   │
│  (J2)    header   (SW2) testpad │
│  [trái]  [phải]                 │
└──────────────────────────────────┘
```

**Vị trí cụ thể đề xuất (gốc tọa độ dưới-trái):**
- U3 (ESP32-C3-MINI-1): trung tâm board — x=20, y=20
  - Module hướng antenna lên trên (y=25..40)
- J1 (USB-C): cạnh dưới — x=12, y=0.5
- U1 (BQ24074): x=10, y=8
- U2 (AP2112K): x=22, y=6
- D2 (USBLC6-2SC6): x=8, y=4 (gần USB-C)
- F1 (PTC VBUS): x=16, y=5
- D1 (TVS): x=14, y=4
- J2 (JST-PH): cạnh trái — x=0, y=20 (xoay 90°)
- DS1 (OLED header): cạnh phải — x=37, y=20
- SW2 (BOOT button): x=30, y=10
- Test pads (UART, SCL, GND, 3V3): cạnh trên — x=5..20, y=38
- R_CC1, R_CC2 (5.1k): gần J1
- F2 (PTC VBAT): gần J2
- R_ISET, R_ILIM, R_TS: gần U1
- BSS138 + divider (R10/R11/R12 + C9): gần U3 góc y=25..30
- R7/R8/R9 (encoder pull-ups): gần header encoder

### 1.3 Encoder PEC11R — Quyết định đặc biệt

PEC11R-4215F-S0024 body 12.5×13.4mm → **KHÔNG fit trong 40×40mm** cùng với ESP32-C3 module.

**Lựa chọn:**
1. **Off-board encoder** — Header 5-pin (A, B, SW, C, GND) + flex cable → encoder gắn trên khung/enclosure riêng
   - Recommended cho 40×40mm
   - Giữ nguyên firmware (GPIO2/3/4)
   - Cần chọn connector nhỏ (Molex PicoBlade 1.25mm hoặc JST SH 1.0mm)
2. **THT encoder on edge** — Đặt PEC11R chồm ra ngoài board edge, phần body nằm ngoài PCB
   - Phần thân encoder nằm ngoài board, chỉ pins + support pads trên PCB
   - Cần kiểm tra cơ khí với enclosure
3. **Bỏ encoder** → chỉ dùng nút, mất navigation UX

**Đã chọn: Option 1 (off-board, header 5-pin)** — đơn giản, linh hoạt.

Chi tiết header encoder:
- Connector: JST SH 1.0mm 5-pin (hoặc Molex PicoBlade 1.25mm)
- Pins: 1 = GND, 2 = C (common), 3 = A, 4 = B, 5 = SW
- Pull-ups (10k) vẫn ở main board
- Debounce cap (10nF) optional trên main board

### 1.4 Kiểm tra JLCPCB assembly constraints

| Item | Yêu cầu |
|---|---|
| PCB panelization | 40×40mm OK (≥10×10mm) |
| Min component | 0402 OK, dùng 0603 cho dễ |
| ESP32-C3-MINI-1-N4 | Kiểm tra stock JLCPCB (là basic part?) |
| BQ24074RGTR | Kiểm tra stock (WQFN-20) |
| TYPE-C-31-M-12 | Kiểm tra stock |
| USBLC6-2SC6 | Kiểm tra stock |
| BSS138 | Standard part |
| AP2112K-3.3TRG1 | Kiểm tra stock |
| Extended parts | Nếu cần, chấp nhận phí extended component |

---

## PHASE 2: ROUTING — 3 ngày

### 2.1 Net classes (KiCad)
| Net Class | Width | Gap | Via | Layer |
|---|---|-----|-----|---|
| POWER_HIGH (VBUS, SYS_RAW) | 0.5mm | 0.2mm | 0.6/0.3mm | F.Cu → via → In2.Cu/PWR |
| POWER_BAT (VBAT, BAT_CONN+) | 0.5mm | 0.2mm | 0.6/0.3mm | F.Cu → In2.Cu/PWR |
| POWER_3V3 (3V3) | 0.4mm | 0.2mm | 0.6/0.3mm | F.Cu → star topology |
| GND | 0.4mm | 0.2mm | 0.6/0.3mm | In1.Cu plane |
| USB_DIFF (D+/D-) | 0.3mm | 0.15mm | — | **F.Cu only** — no vias |
| SIGNAL (I2C, UART, ENC) | 0.25mm | 0.2mm | 0.6/0.3mm | F.Cu / B.Cu |
| ANALOG (BAT_ADC) | 0.25mm | 0.25mm | 0.6/0.3mm | F.Cu, guard ring |

### 2.2 Manual routing sequence (quan trọng — theo đúng thứ tự)

1. **USB diff pair** (D+/D-) — ưu tiên #1
   - F.Cu, 90Ω differential, không via
   - USBLC6 → ESP32-C3 D+/D- pins
   - Length match <2mm
2. **Power routing manual**
   - VBUS: J1 → F1 → U1(IN)
   - SYS_RAW: U1(OUT) → U2(VIN)
   - 3V3: U2(VOUT) → U3, DS1, pull-ups
   - VBAT: U1(BAT) → F2 → J2
3. **BQ24074 support**
   - CE, CHG, FAULT → ESP32-C3 GPIO5/6/7
   - ISET (R3=1.1k), ILIM (R4=2.0k)
   - TS divider (R5, R6 = 10k)
   - Decoupling caps sát pins U1
4. **AP2112K capacitor loops** (C1, C2 sát U2)
5. **I2C** (SCL=GPIO10, SDA=GPIO8)
6. **UART debug** (TX=GPIO21, RX=GPIO20)
7. **Encoder/BOOT header** signals
8. **Gated ADC** (BSS138 + divider + filter)
9. **GND stitching vias** — ≥8 vias quanh module U3

### 2.3 In1.Cu GND plane
- Liên tục, không split
- Antenna keepout ≥15mm từ module antenna edge (tra datasheet MINI-1-N4)
- Thermal vias cho BQ24074 EP (≥4×0.3mm)

### 2.4 In2.Cu PWR plane
- Power distribution (SYS_RAW, VBAT)
- Không signal routing trên In2

### 2.5 DRC target
- 0 errors
- 0 unconnected
- 0 clearance violations
- Chấp nhận warning-only: `lib_footprint_mismatch` (nếu có)

---

## PHASE 3: MANUFACTURING EXPORT — 1 ngày

### 3.1 JLCPCB fabrication outputs
- Gerber X2 (JLCPCB format)
  - F.Cu, In1.Cu_GND, In2.Cu_PWR, B.Cu
  - F.Mask, B.Mask
  - F.SilkS, B.SilkS
  - F.Paste, B.Paste
  - Edge.Cuts
  - Drill: PTH + NPTH
- Output: `hardware/fabrication/roadping-c3-mini-usbc-bq24074/`

### 3.2 JLCPCB assembly BOM
Format JLCPCB CPL + BOM CSV:
- **BOM CSV:** Reference, MPN, Manufacturer, Qty, Value, Package, JLCPCB Part #
- **CPL/PNP CSV:** Reference, X, Y, Rotation, Layer (top/bottom)

### 3.3 JLCPCB special requirements
- **PCB Qty:** 5 assembled + 5 bare
- **PCBA side:** Top-side assembly only (bottom-side = test pads)
- **Stencil:** Include (JLCPCB default)
- **PCB color:** Green (default)
- **Surface finish:** ENIG (JLCPCB standard)
- **Copper weight:** 1oz all layers

### 3.4 Design for JLCPCB checklist
- [ ] Tất cả component có sẵn ở JLCPCB (basic/standard/extended)
- [ ] Không dùng part out-of-stock
- [ ] BOM CSV format đúng JLCPCB template
- [ ] Placement file (CPL) format đúng
- [ ] Panelization? 40×40mm, edge rails nếu cần
- [ ] LCSC part numbers cho mỗi component

### 3.5 Gerber review
- Xem từng layer preview (F.Cu, In1, In2, B.Cu, F.Mask, F.SilkS)
- Kiểm tra antenna keepout
- Kiểm tra silkscreen labels đọc được
- Kiểm tra drill map

---

## PHASE 4: FIRMWARE MIGRATION — 2 ngày (chạy song song)

### 4.1 Sửa `board_config.h`
```c
#define BOARD_NAME "RoadPing-C3-Mini"
#define BOARD_REVISION "EVT-1"
#define FIRMWARE_VERSION "0.2.0"

// ADC divider: 470k+470k gated (ratio=2.0)
#define BAT_ADC_R_TOP_OHMS 470000U
#define BAT_ADC_R_BOTTOM_OHMS 470000U
// compile-time check: ratio = 2.0
#define BAT_ADC_DIVIDER_MULTIPLIER 2.0f

// Thresholds with gated ADC (VBAT×0.5)
#define BOARD_BATTERY_LOW_MV 3500U
#define BOARD_BATTERY_CRITICAL_MV 3300U
```

### 4.2 Sửa `board_pins.h`
```c
#define BOARD_PIN_USB_DP         19
#define BOARD_PIN_USB_DN         18
#define BOARD_PIN_CHARGER_CE      5
#define BOARD_PIN_CHARGER_CHG     6
#define BOARD_PIN_CHARGER_FAULT   7
#define BOARD_PIN_BAT_GATE        1
// Các pin còn lại giữ nguyên (UART, I2C, encoder, ADC)
```

### 4.3 USB-SERIAL-JTAG console
- sdkconfig: `CONFIG_ESP_CONSOLE_USB_SERIAL_JTAG=y`
- UART GPIO20/21 giữ làm test pads fallback
- Partition table: 4MB, 2 OTA (`CONFIG_PARTITION_TABLE_TWO_OTA=y`)

### 4.4 Tạo `components/charger_bq24074/`
Component mới với API:
```c
typedef enum {
    CHARGER_SRC_USB,        // USB present, battery charging or done
    CHARGER_CHARGING,       // /CHG=low, /FAULT=high
    CHARGER_DONE,           // /CHG=high, /FAULT=high
    CHARGER_FAULT,          // /FAULT=low
    CHARGER_BATTERY_ONLY,   // No USB
} charger_state_t;

esp_err_t charger_init(void);
charger_state_t charger_get_state(void);
bool charger_is_usb_present(void);
```

### 4.5 Sửa battery ADC
- GPIO1 HIGH → delay 500ms → ADC read → GPIO1 LOW
- `adc1_config_channel_atten(ADC1_GPIO0_CHANNEL, ADC_ATTEN_DB_11)`
- Sample interval: 30-60s

### 4.6 Component KHÔNG cần sửa
- `display_sh1106` — giữ nguyên
- `encoder` — giữ nguyên (cùng GPIO2/3/4)
- `ui` — giữ nguyên
- `notification_store` — giữ nguyên
- `settings` — giữ nguyên
- `ble_ancs` — giữ nguyên
- `CMakeLists.txt` — giữ nguyên

---

## PHASE 5: BOM HOÀN CHỈNH — 1 ngày

### 5.1 BOM tracking
| Ref | MPN | Qty | Package | JLCPCB Part # | Cost |
|-----|-----|:---:|---|:---:|:----:|
| U3 | ESP32-C3-MINI-1-N4 | 1 | 42-pin cast. module | ? | ~$2.50 |
| U1 | BQ24074RGTR | 1 | WQFN-20 | ? | ~$1.20 |
| U2 | AP2112K-3.3TRG1 | 1 | SOT-23-5 | C12345 | ~$0.15 |
| D2 | USBLC6-2SC6 | 1 | SOT-23-6 | ? | ~$0.30 |
| D1 | PESD5V0S1BA | 1 | SOD-323 | ? | ~$0.10 |
| Q1 | BSS138 | 1 | SOT-23 | C12345 | ~$0.05 |
| J1 | TYPE-C-31-M-12 | 1 | 16-pin SMT | ? | ~$0.35 |
| J2 | B2B-PH-K-S | 1 | 2-pin THT | ? | ~$0.15 |
| F1,F2 | 1206L110SLWR | 2 | 1206 | ? | ~$0.15 |
| R_CC1,R_CC2 | 5.1kΩ 0603 | 2 | 0603 | C12345 | ~$0.02 |
| R_ISET | 1.1kΩ 0603 | 1 | 0603 | C12345 | ~$0.01 |
| R_ILIM | 2.0kΩ 0603 | 1 | 0603 | C12345 | ~$0.01 |
| R_TS1,R_TS2 | 10kΩ 0603 | 2 | 0603 | C12345 | ~$0.02 |
| R_CE,R_CHG,R_FLT | 10kΩ 0603 | 3 | 0603 | C12345 | ~$0.03 |
| R_ENC1,2,3 | 10kΩ 0603 | 3 | 0603 | C12345 | ~$0.03 |
| R_ADC_TOP | 470kΩ 0603 | 1 | 0603 | C12345 | ~$0.01 |
| R_ADC_BOT | 470kΩ 0603 | 1 | 0603 | C12345 | ~$0.01 |
| R_GATE_PD | 100kΩ 0603 | 1 | 0603 | C12345 | ~$0.01 |
| C_VBUS_IN | 10µF 0603 | 1 | 0603 | C12345 | ~$0.05 |
| C_VBUS_BYP | 0.1µF 0603 | 1 | 0603 | C12345 | ~$0.01 |
| C_SYS_IN | 10µF 0603 | 1 | 0603 | C12345 | ~$0.05 |
| C_SYS_BYP | 0.1µF 0603 | 1 | 0603 | C12345 | ~$0.01 |
| C_BAT | 1µF 0603 | 1 | 0603 | C12345 | ~$0.02 |
| C_IN_LDO | 1µF 0603 | 1 | 0603 | C12345 | ~$0.01 |
| C_OUT_LDO | 1µF 0603 | 1 | 0603 | C12345 | ~$0.01 |
| C_BULK_3V3 | 10µF 0603 | 1 | 0603 | C12345 | ~$0.05 |
| C_DEC_3V3 | 0.1µF 0603 | 4 | 0603 | C12345 | ~$0.04 |
| C_ADC_FILT | 0.1µF 0603 | 1 | 0603 | C12345 | ~$0.01 |
| DS1 | SH1106 OLED 128x64 | 1 | 4-pin module | — | ~$5.00 |
| SW1 | PEC11R-4215F-S0024 | 1 | Radial THT | — | ~$1.20 |
| | | | **Estimated total BOM** | | **~$11.50** |

### 5.2 Kiểm tra JLCPCB stock
Cần tra cứu LCSC part number cho từng component trước khi đặt.
Những part critical:
- **ESP32-C3-MINI-1-N4** — nếu JLCPCB không stock, có thể mua riêng và gửi kèm (customer parts)
- **BQ24074RGTR** — WQFN-20, thường có stock
- **TYPE-C-31-M-12** — LCSC part C398303

---

## PHASE 6: SẴN SÀNG ĐẶT HÀNG + TEST — 1 ngày

### 6.1 Pre-order checklist
- [ ] ERC: 0 violations
- [ ] DRC: 0 errors, 0 unconnected, 0 clearance
- [ ] Schematic parity: 0 issues
- [ ] BOM CSV xuất đúng format JLCPCB
- [ ] PNP/CPL CSV xuất đúng format
- [ ] Gerber preview OK (từng layer)
- [ ] Antenna keepout clear trên 4 layers
- [ ] Silkscreen labels đọc được
- [ ] JLCPCB impedance coupon cho 90Ω diff pair
- [ ] PCB dimension = 40×40mm

### 6.2 Order JLCPCB
- 5× assembled (top-side)
- 5× bare PCBs
- Lead time: 5-8 ngày (PCB) + 3-5 ngày (assembly)

### 6.3 Chờ board + bring-up
Khi có board, theo trình tự bring-up trong `docs/11_BRINGUP_AND_TEST.md`.

---

## SCHEDULE TỔNG THỂ

| Phase | Task | Days | Bắt đầu | Kết thúc |
|:-----:|---|:----:|:---:|:---:|
| 0 | Critical fixes | 0.5 | D0 | D0 |
| 1 | Placement 40×40mm | 2 | D0.5 | D2.5 |
| 2 | Routing | 3 | D2.5 | D5.5 |
| 3 | Manufacturing export | 1 | D5.5 | D6.5 |
| 4 | Firmware migration | 2 | D0 | D2 (song song) |
| 5 | BOM hoàn chỉnh | 1 | D5.5 | D6.5 |
| 6 | Order + test prep | 1 | D6.5 | D7.5 |

→ **ORDER ngày D7-D8** (khoảng 25-26/06)
→ **Board về D12-D15** (khoảng 01-04/07)

---

## VẤN ĐỀ CẦN QUYẾT ĐỊNH

| # | Issue | Lựa chọn |
|:-:|---|---|
| 1 | **PEC11R encoder** | Off-board (header 5-pin + flex) — khuyến nghị |
| 2 | **JLCPCB ESP32-C3-MINI-1 stock** | Nếu out-of-stock → gửi kèm (customer part) |
| 3 | **BQ24074 PG pin** (pin 17) | NC hay nối LED? Hiện tại NC |
| 4 | **USB series resistor** | 27Ω trên D+/D-? Cần hay không? (JLCPCB có 0Ω option) |
| 5 | **NTC on battery** | Phase 2, bỏ qua cho EVT này |

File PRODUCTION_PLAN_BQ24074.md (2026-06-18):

# RoadPing-C3 Mini USB-C BQ24074 — Production Plan (Full)

> **Project:** `hardware/kicad/roadping-c3-mini-usbc-bq24074/`  
> **Key IC:** BQ24074RGTR (power-path charger) + ESP32-C3-MINI-1-N4 + USB-C native  
> **Board:** 4-layer, 40×50mm, all 83 SMD on Top  
> **Date:** 2026-06-17  
> **Status:** CAD_REPAIR_IN_PROGRESS — schematic ERC not clean, PCB/parity not closed, new LDO decoupling caps not yet placed/routed on PCB  
> **Firmware:** NOT migrated (still on Super Mini pinout)

---

## MỤC LỤC

- [Phase 0: Project Overview & Health](#phase-0-project-overview--health)
- [Phase 1: PCB Closure — KiCad GUI](#phase-1-pcb-closure--kicad-gui)
- [Phase 2: BOM Lock & Sourcing](#phase-2-bom-lock--sourcing)
- [Phase 3: Fabrication Package](#phase-3-fabrication-package)
- [Phase 4: Firmware Migration](#phase-4-firmware-migration)
- [Phase 5: Validation & Test](#phase-5-validation--test)
- [Phase 6: Production Release](#phase-6-production-release)

---

## PHASE 0: PROJECT OVERVIEW & HEALTH

### Current Status

```
┌────────────────────────────────────────────────────────────┐
│                    ROADPING-C3 BQ24074                      │
│  Schematic: ❌ DRAFT, ERC not clean (156 violations)        │
│  PCB:       ❌ Openable after restore; DRC/parity not closed│
│  BOM:       ✅ 32 components, 19 LCSC PNs (62% MPN)        │
│  Firmware:  ❌ Still on Super Mini — NOT migrated           │
│  EMC:       ⚠️  Analyzer-only; must rerun after GND fill    │
│  Assembly:  ⚠️  Top-side intent only; not DVT released      │
└────────────────────────────────────────────────────────────┘
```

### Key Differences from EVT v2 (TP4056 → BQ24074)

| Aspect | EVT v2 (old) | BQ24074 (current) |
|---|---|---|
| Charger | TP4056 module (no power-path) | BQ24074RGTR (power-path, NTC, status outputs) |
| USB | External module via pin header | Native TYPE-C-31-M-12 + USBLC6-2SC6 ESD |
| ESP32 | Super Mini (third-party module) | ESP32-C3-MINI-1-N4 (official Espressif) |
| PCB | 2-layer, 19 SMD on bottom | 4-layer, 83 SMD all on top |
| Battery ADC | Direct divider (R6/R7) | Gated via BSS138 (saves power) |
| GPIOs | 8 used | 15 used (new: GPIO1/5/6/7 for charger) |
| BOM cost | ~$14/board | ~$9.10/board |

### 5 Unrouted Nets (BLOCKER)

> **Staleness note:** this table came from an earlier analyzer snapshot. Current DRC/parity cannot be accepted until KiCad can run full DRC with schematic parity on the active PCB.

| Net | Pins | Why missing |
|-----|---|---|
| Net-(J1-GND-PadA1) | J1 GND pads | USB-C shield GND daisy chain |
| Net-(J1-VBUS-PadA4) | J1 VBUS pads | VBUS from USB-C to BQ24074 |
| Net-(J1-SHIELD-PadSH) | J1 SHIELD pads | USB-C shield stitching |
| USB_DN_C3 | R13, R14 | USB DN termination resistors |
| ISET | R3, U1 | BQ24074 charge current set resistor |

**Fix:** Route these → fill GND zone → 0 DRC errors.

### Current CAD Evidence — 2026-06-18

| Item | Current evidence | Status |
|---|---|---|
| Schematic ERC | `hardware/kicad/roadping-c3-mini-usbc-bq24074/ERC_AFTER_EN_LDO_CAPS_RESTOREPCB_2026-06-18.txt`: 156 violations | BLOCKER |
| PCB openability | KiCad Python `LoadBoard()` succeeds after restore from `.history`, 83 footprints | PARTIAL |
| DRC/parity | `kicad-cli pcb drc --schematic-parity` aborts with exit `134`; no report generated | BLOCKER |
| New LDO caps | `C_IN_LDO`, `C_OUT_LDO`, `C_BULK_3V3` added to schematic only | PCB_SYNC_REQUIRED |
| Release status | No fabrication/export approval | NO-GO |

### Current Layout Issues (from analyzers)

| Issue | Severity | Source |
|---|---|---|
| 5 nets unrouted | 🔴 BLOCKER | PCB analyzer |
| No GND copper pour | 🔴 BLOCKER | EMC GP-002 |
| No fiducial markers | 🔴 BLOCKER | PCB FD-001 |
| BQ24074: No decoupling cap near U1 | 🔴 BLOCKER | EMC DC-002 |
| BQ24074: No thermal vias under U1 | 🟡 HIGH | PCB TV-001 |
| lib_footprint_mismatch (~27 items) | 🟡 HIGH | PCB |
| Stackup: 4 signal layers no ground plane | 🟡 HIGH | EMC SU-001 |
| SW1, SW2 missing silk labels | 🟡 HIGH | Silkscreen docs |
| R_CE, R_CHG, R_FLT no LCSC PN | 🟡 HIGH | BOM gaps |
| DS1 (OLED) no MPN/LCSC | 🟡 HIGH | BOM gaps |
| 3 rails missing PWR_FLAG | ℹ️ LOW | Schematic RS-001 |
| U2.EN, U3.CHIP_EN missing pull-up | ℹ️ LOW | Schematic PU-001 |

---

## PHASE 1: PCB CLOSURE — KiCad GUI

> **Skill: `kicad`** — Schematic/PCB analysis, DRC/ERC  
> **Tool:** KiCad 10 PCB Editor (GUI)  
> **Location:** `hardware/kicad/roadping-c3-mini-usbc-bq24074/roadping-c3-mini-usbc-bq24074.kicad_pcb`  
> **Target:** 0 DRC errors + 0 ERC errors + fabrication-ready PCB

### Step 1.0 — Open Project Correctly

Do **not** open `roadping-c3-mini-usbc-bq24074.kicad_pcb` directly in standalone PCB Editor.

Required workflow:

1. Open KiCad Project Manager.
2. Open `hardware/kicad/roadping-c3-mini-usbc-bq24074/roadping-c3-mini-usbc-bq24074.kicad_pro`.
3. Open Schematic Editor from Project Manager.
4. Run ERC and fix schematic issues first.
5. Use `Tools -> Update PCB from Schematic...` only from project context.

### Step 1.0A — ERC Repair Before Routing

Current ERC is not clean. Before PCB routing/fab work, fix all schematic connectivity issues caused by unsnapped wires, dangling labels, unconnected pins, or ambiguous power rails.

Minimum closure criteria:

```yaml
ERC errors: 0
Known intentional NC pins: marked with No Connect
Power rails: driven or documented with PWR_FLAG where required
U2.EN: tied to valid enable source
U3.CHIP_EN: pulled up through R13
No multiple-net-name conflicts
```

### Step 1.0B — Sync New LDO Decoupling Caps

The following schematic-level additions must be synced to PCB before any DVT/fab package:

```yaml
C_IN_LDO:   1uF 0603, SYS_RAW-to-GND, close to AP2112K VIN
C_OUT_LDO:  1uF 0603, 3V3-to-GND, close to AP2112K VOUT
C_BULK_3V3: 10uF 0603, 3V3-to-GND, near ESP32/OLED load path
```

Placement requirements:

- Short trace from cap pad to regulator/load rail.
- GND pad via to GND plane within 1 mm where practical.
- Do not place under inaccessible/tall modules.
- Refill zones after placement/routing.

### Step 1.1 — Route 5 Unrouted Nets

Use KiCad PCB Editor → route these manually:

```yaml
Net-(J1-GND-PadA1):   Connect all J1 GND pads (A1, A11, B1, B11, SHIELD)
                       Width: 0.3mm, layer: F.Cu
Net-(J1-VBUS-PadA4):   Connect J1 VBUS pads (A4, A9, B4, B9) → BQ24074 IN
                       Width: 0.5mm, layer: F.Cu
Net-(J1-SHIELD-PadSH): Shield stitching vias near J1 mounting posts
                       Width: 0.3mm
USB_DN_C3:             R13(27Ω) in series with USB_DN trace
USB_DP_C3:             R14(27Ω) in series with USB_DP trace
ISET:                  R3(1.1k) → U1 pin 13 (ISET)
```

**Verify:** View → Connectivity → "Highlight Net" — mỗi net phải highlight tất cả pads của nó.

### Step 1.2 — Fill GND Copper Pour

**Problem:** No GND zone on any layer. EMC GP-002: "No ground plane zones detected."

**Action:**
1. **Inner layer 1** (In1.Cu): **Full GND plane** — Place → Zone → draw board outline → net: `GND`
2. **Inner layer 2** (In2.Cu): **Full GND plane** — same
3. **F.Cu**: GND pour với clearance 0.3mm — để hở antenna keepout
4. **B.Cu**: GND pour với clearance 0.3mm

**Stackup sau fix:**
```
F.Cu  — Signal + GND pour
In1.Cu — GND PLANE     ← (new)
In2.Cu — GND PLANE     ← (new)
B.Cu  — Signal + GND pour
```

**Lợi ích:**
- Giải quyết 20 "unrouted GND daisy chains" (FreeRouting report)
- EMC: reference plane cho tất cả signal tracks
- Cung cấp return path ngắn cho high-speed (USB DP/DN)
- Tản nhiệt cho BQ24074 WQFN exposed pad

### Step 1.3 — Add Decoupling Caps Near U1 (BQ24074)

**Problem:** EMC DC-002 — "No decoupling cap found near U1."

**Action:** Thêm 2 caps CẠNH U1 (WQFN-20):
```yaml
C_new_1: 1µF 0603, VIN-to-GND, cạnh U1 pin 1 (IN)
C_new_2: 100nF 0603, VIN-to-GND, cạnh U1 pin 1 (IN)
Vias:    Sát pad GND của cap → xuống In1.Cu GND plane
```

**KiCad steps:** Place → Symbol → add to schematic → Annotate → Update PCB from Schematic → Place caps.

### Step 1.4 — Add Thermal Vias Under U1

**Problem:** PCB TV-001 — "Add thermal vias under U1 (need 5, have 0)."
**Risk:** BQ24074 WQFN-20 exposed pad sẽ không thoát nhiệt ở 910mA charge.

**Action:** Thêm 4-6 thermal vias trong exposed pad của U1:
```yaml
Via spec: 0.4mm drill, 0.7mm pad
Placement: 2×3 grid inside EP (2.7×2.7mm)
Connection: GND (EP is GND on BQ24074)
Tenting: UNTENTED (solder will fill during reflow)
```

**KiCad:** View → Via → đặt vào giữa EP footprint → Right-click → Properties → net=GND.

### Step 1.5 — Add Fiducial Markers

**Problem:** PCB FD-001 — "Add fiducial markers for pick-and-place."

**Action:** Add 3x `Fiducial:Fiducial_1mm_Mask3mm`:
```yaml
FID1: (13, 13)  — bottom-left
FID2: (47, 13)  — bottom-right
FID3: (13, 57)  — top-left
Exclude from BOM: Yes
```

### Step 1.6 — Resolve lib_footprint_mismatch Warnings

**Action:** Tools → Update Footprints from Library → chọn:
```
Standard (Update from library):
  C_0603_1608Metric, R_0603_1608Metric, SOT-23, SOT-23-5
  SOD-323, SOD-123, Fuse_1206_3216Metric
  WQFN-20-1EP, USB_C_Receptacle, PinHeader_1x02

Custom (Keep local):
  OLED_4PIN_VDD_GND_SCK_SDA_2.54MM
  MODULE_ESP32-C3-MINI-1-N4
  TP_Round_1.0mm
  XDCR_PEC11R-4215F-S0024
```

### Step 1.7 — Final DRC + ERC

**DRC Run:**
```bash
# Command-line check (if kicad-cli available)
kicad-cli pcb drc roadping-c3-mini-usbc-bq24074.kicad_pcb \
  --schematic-parity --output reports/drc_production.rpt
```

**DRC Target:**
```
ERROR gate:      0 errors, 0 unconnected
Full DRC:        0 errors, 0 warnings
Clearance:       0 (0.2mm min)
Shorts:          0
Silkscreen/pad:  0
Unrouted:        0
```

**ERC Target:**
```
Errors:   0
Warnings: accept PWR_FLAG warnings if documented
```

### Step 1.8 — Silkscreen Polish

Fix silkscreen warnings:
```
SW1: add "ENCODER" silk near right edge
SW2: add "BOOT" silk near TP pads
OLED: verify "VDD GND SCL SDA" silk at DS1 header
J2:  verify "BAT+" "BAT-" polarity silk
D2:  verify TVS cathode marking (bar)
Board name: add "RoadPing-C3" + "BQ24074" + "REV A" on F.SilkS
```

### Step 1.9 — Fix Decoupling Cap Via Proximity

EMC DC-003: C1, C2, C3, C4, C5, C6 via connection xa.

**Action:** Mỗi cap cần có via GND sát pad GND của cap — không quá 1mm. Dùng trace ngắn + rộng.

### Step 1.10 — Fix Stackup EMC Warning

EMC SU-001: "Adjacent signal layers: F.Cu, In1.Cu" — In1.Cu và In2.Cu đều là signal layers.

**Fix:** Chuyển In1.Cu và In2.Cu thành **GND planes**. Chỉ dùng F.Cu + B.Cu cho signal. Với 4-layer và GND planes ở inner, board sẽ có EMC tốt hơn 2-layer.

**Stackup mới:**
```yaml
F.Cu  — Signal + thin GND pour
In1.Cu — GND PLANE (solid, no breaks)
In2.Cu — GND PLANE (solid, no breaks)
B.Cu  — Signal + thin GND pour
```

---

## PHASE 2: BOM LOCK & SOURCING

> **Skills: `bom`, `lcsc`, `digikey`, `mouser`, `element14`, `datasheets`**  
> **Target:** 100% MPN coverage, 100% LCSC/DigiKey PN, verified stock

### Step 2.1 — Run BOM Analysis

**Skill: `bom`**

```bash
python3 <bom-skill>/scripts/bom_manager.py analyze \
  roadping-c3-mini-usbc-bq24074.kicad_sch --json --recursive
```

**Verify:**
- [ ] 32/32 components recognized
- [ ] All values parsed correctly
- [ ] Footprint assignments verified
- [ ] DNP policy decided (C9 debounce, I2C pull-ups)

### Step 2.2 — Fill Remaining Gaps (4 missing MPNs)

Current BOM gaps:

| Ref | Value | Missing | Skill |
|-----|---|---|---|
| DS1 | SH1106 OLED | MPN + LCSC | Search `lcsc` for "SH1106 OLED 128x64 I2C" |
| R_CE, R_CHG, R_FLT | 10k 0603 | LCSC only (MPN fixed: RC0603FR-0710KL) | `lcsc` C98220 |
| SW2 | BOOT header 1x02 | MPN + LCSC | `lcsc` C492401 (same as EVT v2 J1) |
| TP_RX, TP_TX | Test pads | No MPN needed (PCB-only) | Skip |

**Skill: `lcsc`** — Search and verify:

```bash
python3 <lcsc-skill>/scripts/sync_datasheets_lcsc.py \
  --mpn-list mpns.txt --output ./datasheets
```

### Step 2.3 — Sync Datasheets

**Skill: `datasheets`**

Download datasheets cho tất cả parts có MPN:

| Part | MPN | Datasheet URL |
|---|-----|---|
| BQ24074 | BQ24074RGTR | https://www.ti.com/lit/ds/symlink/bq24074.pdf |
| ESP32-C3-MINI-1 | ESP32-C3-MINI-1-N4 | Espressif website |
| AP2112K-3.3 | AP2112K-3.3TRG1 | Diodes website |
| USBLC6-2SC6 | USBLC6-2SC6 | ST website |
| PESD5V0S1BA | PESD5V0S1BA | Nexperia website |
| BSS138 | BSS138 | ON Semi website |
| PEC11R | PEC11R-4215F-S0024 | Bourns |
| MF-SM013/250-2 | MF-SM013/250-2 | Bourns |
| TYPE-C-31-M-12 | TYPE-C-31-M-12 | HRO |

**Action:** Download PDFs to `datasheets/` and run:
```bash
python3 <datasheets-skill>/scripts/extract_datasheet.py datasheets/bq24074.pdf
python3 <datasheets-skill>/scripts/extract_datasheet.py datasheets/esp32-c3-mini-1.pdf
```

### Step 2.4 — Generate BOM Order Files

**Skill: `bom`**

```bash
# Export BOM tracking CSV
python3 <bom-skill>/scripts/bom_manager.py export \
  roadping-c3-mini-usbc-bq24074.kicad_sch \
  -o bom/production_bom.csv --recursive

# Generate per-distributor order files
python3 <bom-skill>/scripts/bom_manager.py order \
  bom/bom.csv --boards 5 --spares 2
```

### Step 2.5 — LCSC Order Verification

**Skill: `lcsc`**

Verify stock + pricing for all 19 LCSC PNs:

| LCSC Part | Part | Stock | Qty Order | Giá |
|:---:|---|:----:|:---:|:---:|
| C5673 | 1µF 0603 | Samsung | ~1.8M | 8 |
| C19702 | 10µF 0603 | Samsung | ~28M | 5 |
| C1591 | 100nF 0603 | Samsung | ~10M | 5 |
| C5261083 | PESD5V0S1BA | Nexperia | ~166k | 3 |
| C2687116 | USBLC6-2SC6 | ST | — | 2 |
| C720650 | PTC 1.1A | Bourns | — | 4 |
| C2907321 | TYPE-C-31-M-12 | HRO | — | 1 |
| C131337 | JST PH | JST | ~267k | 3 |
| C112239 | BSS138 | ON Semi | — | 3 |
| C105580 | 5.1k 0603 | Yageo | — | 5 |
| C137780 | 1.1k 0603 | Yageo | — | 2 |
| C105576 | 2.0k 0603 | Yageo | — | 2 |
| C98220 | 10k 0603 | Yageo | ~5.5M | 10 |
| C114622 | 470k 0603 | Yageo | — | 4 |
| C14675 | 100k 0603 | Yageo | — | 2 |
| C143790 | PEC11R | Bourns | ~797 | 1 |
| C54313 | BQ24074RGTR | TI | — | 3 |
| C23380830 | AP2112K-3.3 | Diodes | ~53k | 3 |
| C2838502 | ESP32-C3-MINI-1-N4 | Espressif | ~16k | 3 |

**Total LCSC order:** ~$7-10 + shipping ~$5-8 = **~$15**

### Step 2.6 — Special Order Parts (Non-LCSC)

| Part | Nguồn | Giá |
|---|---|:---:|
| SH1106 OLED 128x64 I2C | AliExpress | ~$5 |
| F1/F2: 1206L110SLWR or MF-SM013/250-2 | DigiKey | ~$0.50 |
| DS1 OLED module jumper wires | Amazon | ~$2 |

**Skill: `digikey`** — Search F1/F2 alternatives:
```bash
python3 <digikey-skill>/search_digikey.py --mpn "1206L110SLWR"
```

---

## PHASE 3: FABRICATION PACKAGE

> **Skills: `jlcpcb`, `pcbway`, `kicad`**  
> **Target:** DVT candidate Gerbers + BOM + CPL. Do not label as production until all production gates pass.

### Step 3.1 — Re-export DVT Candidate Gerbers (After PCB Fixes)

**Skill: `kicad`**

```bash
# Export Gerbers
kicad-cli pcb export gerbers roadping-c3-mini-usbc-bq24074.kicad_pcb \
  --output fabrication/dvt_candidate/gerbers/ \
  --layers F.Cu,In1.Cu,In2.Cu,B.Cu,F.Paste,B.Paste,F.SilkS,B.SilkS,F.Mask,B.Mask,Edge.Cuts \
  --no-x2 --no-protel-ext --subtract-soldermask

# Export Drill
kicad-cli pcb export drill roadping-c3-mini-usbc-bq24074.kicad_pcb \
  --output fabrication/dvt_candidate/drill/ \
  --format excellon --drill-origin absolute

# Export BOM + CPL for JLCPCB
kicad-cli pcb export pos roadping-c3-mini-usbc-bq24074.kicad_pcb \
  --output fabrication/dvt_candidate/cpl.csv --format csv --units mm --side front
```

### Step 3.2 — JLCPCB DVT Order Config

**Skill: `jlcpcb`**

```yaml
fabrication:
  base:
    pcb_qty: 5
    layers: 4
    thickness: 1.6mm
    material: FR-4 TG150
    surface_finish: HASL (lead-free)  # ENIG recommended for USB-C wear
    copper_weight: 1 oz all layers
    solder_mask: Green
    silkscreen: White
    min_track: 0.2mm
    min_hole: 0.3mm
    impedance: none (4-layer, no 90Ω needed — DP traces are short)

  pcb_assembly:
    type: Economic
    side: Top only
    stencil: Included (framed)
    bom_csv: bom/jlcpcb_bom.csv
    cpl_csv: fabrication/dvt_candidate/cpl.csv

  parts_not_on_lcsc:
    DS1: SH1106 OLED — hand solder after SMT reflow
    J2: JST-PH — hand solder (THT)
    SW1: PEC11R — hand solder (THT + shield posts)
    U3: ESP32-C3-MINI-1-N4 — verify LCSC C2838502
```

### Step 3.3 — Generate JLCPCB DVT BOM + CPL

```yaml
jlcpcb_bom.csv format:
  Comment,Designator,Footprint,LCSC Part #
  1uF,"C1,C2",0603,C5673
  10uF,C3,0603,C19702
  ...

jlcpcb_cpl.csv format:
  Designator,Mid X (mm),Mid Y (mm),Rotation (deg),Layer
  C1,44.0,25.0,0,Top
  C2,44.0,32.0,0,Top
  ...
```

### Step 3.4 — Option: PCBWay (if JLCPCB can't source parts)

**Skill: `pcbway`**

Nếu JLCPCB không hỗ trợ ESP32-C3-MINI-1-N4 (module) hoặc BQ24074 (WQFN), dùng PCBWay turnkey:
- PCBWay mua parts bằng MPN (không cần LCSC number)
- Giá cao hơn nhưng global sourcing
- Lead time: 7-12 ngày

---

## PHASE 4: FIRMWARE MIGRATION

> **Skill:** Manual coding (no automated skill)  
> **Location:** `firmware/components/*` + `firmware/main/board_pins.h`  
> **Target:** Firmware chạy trên ESP32-C3-MINI-1-N4 với BQ24074

### Step 4.1 — Update board_pins.h

**KHẤP:** Firmware hiện tại dùng **ESP32-C3 Super Mini**. Cần migrate sang **ESP32-C3-MINI-1-N4**.

**Thay đổi:**
```c
// OLD (Super Mini): GPIOs match yet but need to add new ones
#define BOARD_PIN_UART_TX 21
#define BOARD_PIN_UART_RX 20
#define BOARD_PIN_I2C_SDA 8
#define BOARD_PIN_I2C_SCL 10
#define BOARD_PIN_ENCODER_A 2
#define BOARD_PIN_ENCODER_B 3
#define BOARD_PIN_ENCODER_SW 4

// BQ24074 charger status pins (NEW — not in EVT v2)
#define BOARD_PIN_CHG_CE      5   // GPIO5: Charger Enable (active low pull-up)
#define BOARD_PIN_CHG_STATUS  6   // GPIO6: Charging status (active low)
#define BOARD_PIN_FLT_STATUS  7   // GPIO7: Fault status (active low)

// Gated battery ADC (NEW — BSS138 gate control)
#define BOARD_PIN_BAT_GATE    1   // GPIO1: BSS138 gate, HIGH = ADC active
#define BOARD_BAT_ADC_UNIT    1
#define BOARD_BAT_ADC_CHANNEL 0   // GPIO0 still ADC input
```

### Step 4.2 — Update board_config.h

```c
// OLD: BATTERY DIVIDER R6=220k/R7=100k → Vadc = Vbat * 3.2
// NEW: GATED DIVIDER R10=470k/R12=100k + BSS138 → Vadc = Vbat * 5.7

#define BOARD_FEATURE_BATTERY_ADC 1
#define BOARD_FEATURE_BAT_GATE    1   // NEW
#define BOARD_FEATURE_CHARGER_GPIO 1  // NEW

#define BAT_ADC_R_TOP_OHMS 470000U
#define BAT_ADC_R_BOTTOM_OHMS 100000U
#define BAT_ADC_DIVIDER_MULTIPLIER \
    (((float)BAT_ADC_R_TOP_OHMS + (float)BAT_ADC_R_BOTTOM_OHMS) / \
     (float)BAT_ADC_R_BOTTOM_OHMS)
// = (470k + 100k) / 100k = 5.7  → COMPILE-TIME CHECK THIS

#define BOARD_BATTERY_LOW_MV 3500U
#define BOARD_BATTERY_CRITICAL_MV 3300U

// ADC settling after BSS138 gate enable
#define BAT_ADC_GATE_SETTLE_MS 500U   // R10||R12 || C9 = ~3ms τ, 500ms safe
```

### Step 4.3 — Update battery.c

Add gated ADC logic:
```c
// In battery_read_mv():
// 1. GPIO1 = HIGH (enable BSS138 → divider connects to VBAT)
// 2. vTaskDelay(500ms) // ADC settling
// 3. adc_oneshot_read()
// 4. apply BAT_ADC_DIVIDER_MULTIPLIER (5.7)
// 5. GPIO1 = LOW (save power, divider disconnected)
```

### Step 4.4 — Add Charger Monitor Component

**New component:** `firmware/components/charger_bq24074/`

```c
// charger_bq24074.h
typedef enum {
    CHARGER_STATE_CHARGING,
    CHARGER_STATE_DONE,
    CHARGER_STATE_FAULT,
    CHARGER_STATE_DISABLED,
} charger_state_t;

esp_err_t charger_init(void);
charger_state_t charger_get_state(void);
esp_err_t charger_enable(bool enable);
```

**GPIO mapping:**
```c
GPIO5 (CE_CHG_EN) = output, active low — pull-up 10k (default = enabled)
GPIO6 (CHG_STATUS) = input, active low — 0 = charging
GPIO7 (FLT_STATUS) = input, active low — 0 = fault
```

### Step 4.5 — Update app_main.c

Thêm vào main loop:
```c
// Initialize BQ24074 charger monitor
charger_init();
charger_state_t chg_state = charger_get_state();

// In roadping_task loop:
// - Periodically check charger state (5s interval)
// - Update UI with charging status
// - If FAULT: display error and disable charging
```

### Step 4.6 — Sửa ADC Calibration Scale

ADC voltage divider change: **3.2 → 5.7**
```c
// OLD: Vbat = Vadc * 3.2
// NEW: Vbat = Vadc * (470k + 100k) / 100k = Vadc * 5.7
```

Với divider 470k+100k và 100nF C9, time constant τ = R_thevenin × C = (82k) × 100nF = 8.2ms.
- 5τ = 41ms settling
- Firmware wait: 500ms (safety margin 10×)

### Step 4.7 — I2C OLED Address (Same)

**Không thay đổi** — ESP32-C3-MINI-1-N4 vẫn dùng I2C GPIO8/GPIO10 cho SH1106.

### Step 4.8 — Host Test Verification

**Skill: Manual** — Run existing host tests + add new tests:

```bash
cd firmware/tests/build
cmake .. && make && ./roadping_host_tests
```

Add new test cases:
- [ ] battery.c: test new divider ratio 5.7
- [ ] battery.c: test ADC gate settling timer
- [ ] charger_bq24074.c: state machine unit tests
- [ ] notification_store.c: existing tests still pass

---

## PHASE 5: VALIDATION & TEST

> **Skills: `spice`, `emc`, `kicad`, `kidoc`**  
> **Target:** Physical boards pass all tests

### Step 5.1 — SPICE Simulation of Power Path

**Skill: `spice`**

Simulate BQ24074 power path behavior:
- [ ] BQ24074 startup sequence (VBUS ramp, SYS_RAW rise time)
- [ ] Load transient: 0mA → 150mA (BLE TX peak)
- [ ] USB removal: battery switchover <20µs
- [ ] Battery charge profile: trickle → CC → CV → done
- [ ] BQ24074 power dissipation at 910mA charge

```bash
python3 <spice-skill>/scripts/run_spice.py \
  --schematic analysis/bq24074_schematic.json \
  --subcircuit bq24074_power_path \
  --output analysis/spice/ \
  --simulator ngspice
```

### Step 5.2 — Final EMC Pre-Compliance

**Skill: `emc`**

After GND planes added:
```bash
python3 <emc-skill>/scripts/analyze_emc.py \
  --schematic analysis/bq24074_schematic.json \
  --pcb analysis/bq24074_pcb.json \
  --output analysis/bq24074_emc_final.json \
  --standard fcc-class-b
```

**Target:**
- Risk score: ≤ 30 (improvement from 23.5 after GND fill)
- GP-002: resolved (GND zones added)
- DC-002: resolved (decoupling caps near U1)
- SU-001: resolved (inner layers = GND planes)
- DC-003: resolved (via proximity fixed)

### Step 5.3 — Physical Bring-Up Sequence

Follow `docs/11_BRINGUP_AND_TEST.md`:

```yaml
Step 1: Visual inspection — shorts, polarity, solder bridges
Step 2: Power from USB (no LiPo) — DMM check:
         VBUS=5V, SYS_RAW=4.4V, 3V3=3.3V
Step 3: Flash firmware via UART (TP_TX, TP_RX)
Step 4: I2C scan → OLED at 0x3C
Step 5: Encoder rotation + press test
Step 6: Battery ADC calibration (DMM vs firmware)
         3.0V → 3.7V → 4.2V with bench PSU
         Store calibration factor in NVS
Step 7: BLE ANCS pairing with iPhone
Step 8: Navigation + notification UI test
Step 9: Power-path test:
         USB + battery → charging OK
         Remove USB → no brownout
         Battery only → 8µA BQ sleep
Step 10: Thermal — measure BQ24074 at 910mA charge
```

### Step 5.4 — Generate Documentation Package

**Skill: `kidoc`**

Generate production documentation:
```bash
python3 <kidoc-script> analyze --output docs/production/
```

Documents needed:
- [ ] Hardware Design Description (HDD)
- [ ] Test Report
- [ ] Manufacturing Transfer Package
- [ ] CE/FCC self-declaration

---

## PHASE 6: PRODUCTION RELEASE

> **Hard rule:** the current board is not production-ready. Production release is blocked until real assembled-board evidence, vendor lock, firmware migration, thermal, EMC/ESD, and fixture validation exist.

### Gate Checklist — MUST ALL PASS

```
□ GATE A: PCB
  □ 0 ERC errors before PCB update
  □ 0 DRC errors after zone refill
  □ 0 schematic/PCB parity issues
  □ 0 lib_footprint_mismatch
  □ All 5 unrouted nets connected
  □ GND planes on In1.Cu + In2.Cu
  □ 3 fiducial markers placed
  □ 4+ thermal vias under U1 (BQ24074)
  □ Decoupling caps near U1 (1µF + 100nF)
  □ AP2112K decoupling caps placed/routed (`C_IN_LDO`, `C_OUT_LDO`, `C_BULK_3V3`)
  □ Silkscreen: all labels readible
  □ Gerbers visually reviewed

□ GATE B: BOM
  □ 100% MPN coverage (32/32)
  □ 100% LCSC PN coverage (where available)
  □ BOM cost calculated
  □ LCSC order ready (19 parts, ~$15)
  □ Non-LCSC parts ordered (OLED, PTCs)

□ GATE C: FIRMWARE
  □ board_pins.h migrated to MINI-1-N4
  □ board_config.h updated (divider 5.7, gated ADC)
  □ battery.c gated ADC logic working
  □ charger_bq24074.c component created + tested
  □ ADC calibration routine implemented
  □ Compile-time divider ratio check added
  □ Host tests PASS

□ GATE D: VALIDATION
  □ 3+ boards assembled
  □ Power-path test: USB + battery OK
  □ Battery ADC accurate (±3% after calibration)
  □ BLE ANCS pairing + notifications working
  → Only now: GO_FOR_PRODUCTION
```

---

## TIMELINE

```
Week 1:  PHASE 1 (PCB Closure)
  Day 1-2: Route 5 nets + GND fill + thermal vias
  Day 2-3: Fiducials + decoupling caps + footprint fix
  Day 3-4: DRC/ERC → Gerber export → JLCPCB order
  Day 4-5: LCSC order + AliExpress module orders

Week 2-3: PHASE 4 (Firmware Migration)
  Day 6-8: board_pins.h + board_config.h migration
  Day 8-10: battery.c gated ADC + charger component
  Day 10-12: Host tests + code review

Week 3-4: (Chờ PCB + parts từ JLCPCB/LCSC/AliExpress)

Week 4-5: PHASE 5 (Validation)
  Day 21-25: Board assembly
  Day 25-28: Bring-up + calibration + BLE test
  Day 28-30: Power-path + thermal + EMC check

Week 6:  PHASE 6 (Production Release)
  Day 31-33: Fix any rev2 issues
  Day 34-35: Production order + documentation
```

---

## APPENDIX: SKILL REFERENCE

| Step | Skill | Purpose | Command/Usage |
|---|---|---|---|
| 1.1-1.10 | `kicad` | PCB layout, DRC, ERC, Gerber | `analyze_schematic.py`, `analyze_pcb.py`, `cross_analysis.py` |
| 2.1, 2.4 | `bom` | BOM analysis, export, order | `bom_manager.py analyze/export/order` |
| 2.2, 2.5 | `lcsc` | LCSC part search + datasheet | `sync_datasheets_lcsc.py` |
| 2.3 | `datasheets` | Datasheet extraction | `extract_datasheet.py` |
| 2.6 | `digikey` | DigiKey search | `search_digikey.py` |
| 3.2-3.3 | `jlcpcb` | JLCPCB order config | Template + BOM/CPL upload |
| 3.4 | `pcbway` | PCBWay alternative | Template |
| 5.1 | `spice` | Power-path simulation | `run_spice.py` |
| 5.2 | `emc` | EMC pre-compliance | `analyze_emc.py` |
| 5.4 | `kidoc` | Documentation generation | `kidoc` analysis |

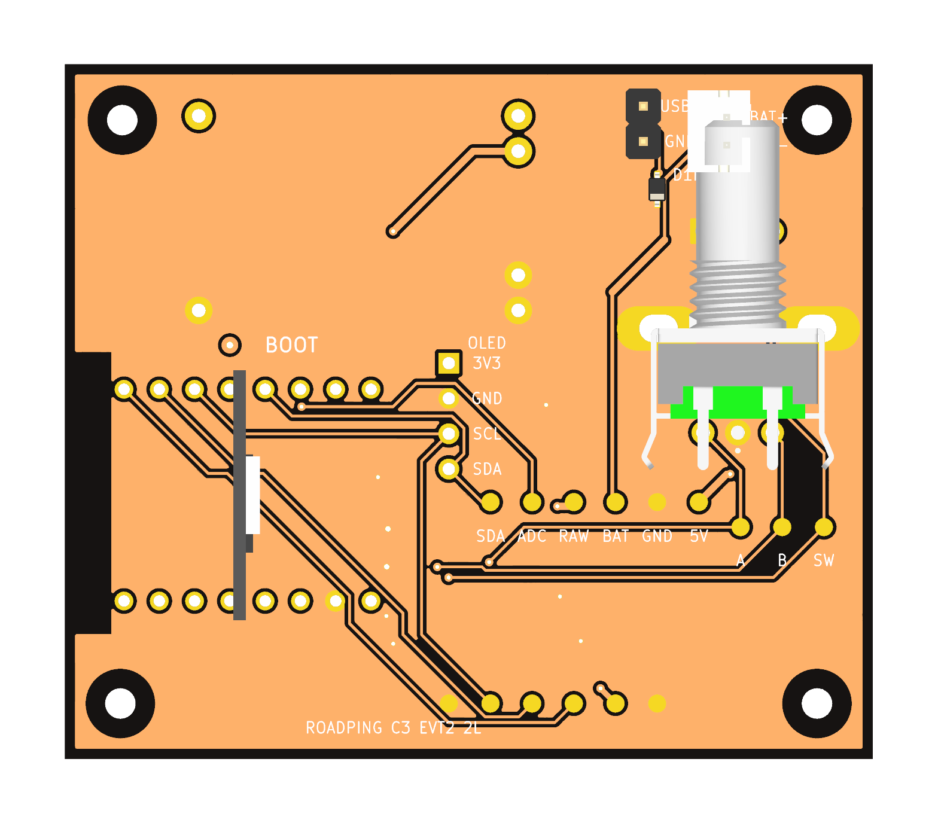
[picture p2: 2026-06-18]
hardware/kicad/roadping-c3-compact-evt-v2/analysis/functional-cluster-live-top.png

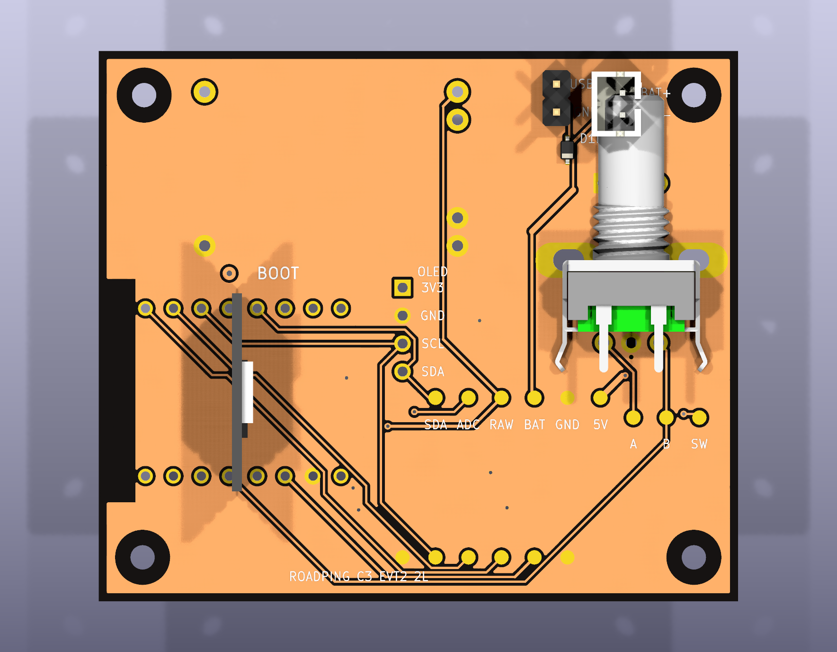
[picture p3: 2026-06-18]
hardware/kicad/roadping-c3-compact-evt-v2/analysis/bottom_opt_final_live_top.png

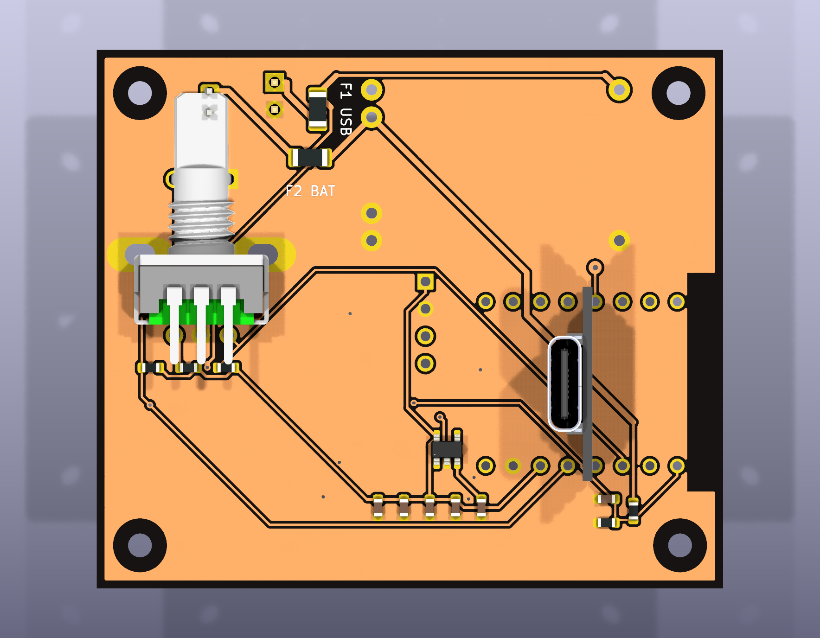
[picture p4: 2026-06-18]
hardware/kicad/roadping-c3-compact-evt-v2/analysis/bottom_opt_final_live_bottom.png

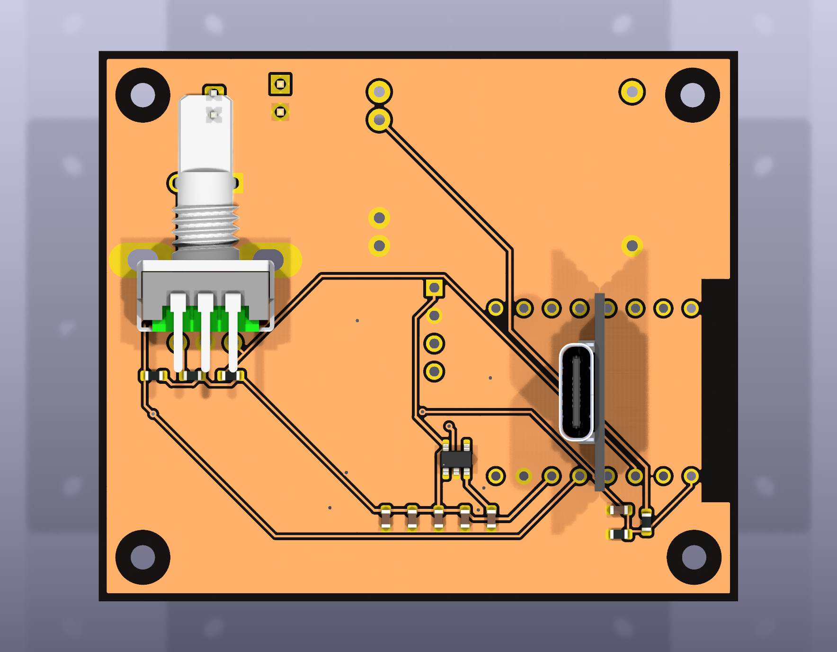
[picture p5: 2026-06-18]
hardware/kicad/roadping-c3-compact-evt-v2/analysis/baseline-bottom.png

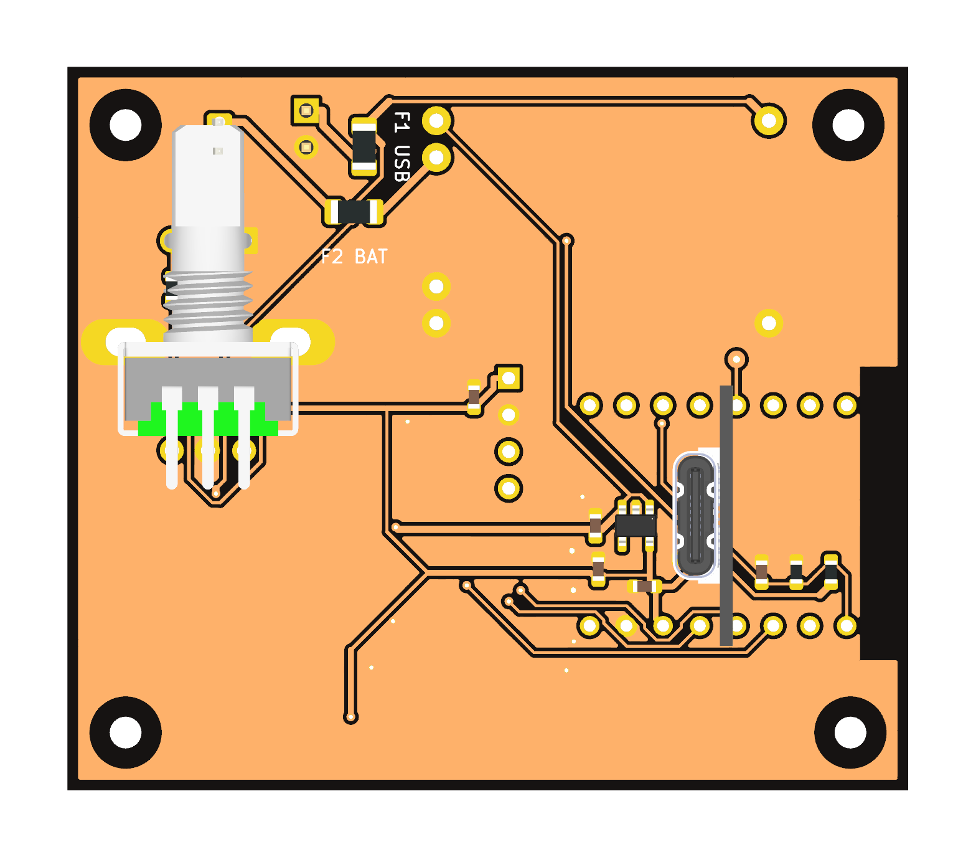
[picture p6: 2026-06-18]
hardware/kicad/roadping-c3-compact-evt-v2/analysis/functional-cluster-live-bottom.png

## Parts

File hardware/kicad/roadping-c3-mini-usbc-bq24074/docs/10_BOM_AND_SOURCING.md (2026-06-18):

# BOM and Sourcing — RoadPing C3 Mini

Full BOM with 28 lines covering all components. See CSV block below or reference spreadsheet.

## Key Components

| Ref | MPN | Qty | Function |
|-----|-----|-----|---|
| U1 | BQ24074RGTR | 1 | LiPo charger, power-path |
| U2 | AP2112K-3.3TRG1 | 1 | 3.3V LDO |
| U3 | ESP32-C3-MINI-1-N4 | 1 | WiFi/BLE module |
| D1 | USBLC6-2SC6 | 1 | USB D+/D- ESD |
| D2 | PESD5V0S1BA | 1 | VBUS TVS |
| Q1 | BSS138 | 1 | ADC gate FET |
| J1 | TYPE-C-31-M-12 | 1 | USB-C receptacle |
| J2 | B2B-PH-K-S | 1 | LiPo connector |
| SW1 | PEC11R-4215F-S0024 | 1 | Rotary encoder |
| DS1 | SH1106 OLED 128x64 | 1 | Display |
| F1,F2 | 1206L110SLWR | 2 | PTC fuses (VBUS + VBAT) |

## Excluded from Previous Design

- TP4056 module (→ replaced by BQ24074)
- D2 Schottky (→ no OR-ing needed)
- Q1 PMOS (→ removed, BQ24074 handles power-path)
- R6/R7 220k/100k (→ replaced by 470k/470k gated)

## Estimated Prototype Cost

| Category | Cost/board (qty 10) |
|---|---|
| ICs + modules | ~$4.50 |
| Discrete semi | ~$0.45 |
| Connectors | ~$1.20 |
| PTC + TVS | ~$0.80 |
| Passives | ~$0.35 |
| Electromechanical | ~$1.80 |
| **Total BOM** | **~$9.10** |
| PCB fabrication (4-layer) | ~$15-25 |
| **Total per board** | **~$25-35** |

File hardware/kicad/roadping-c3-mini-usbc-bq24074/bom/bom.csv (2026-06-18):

Reference | Qty | Value | Footprint | MPN | LCSC | Manufacturer | Chosen_Distributor | Datasheet | Validated | DNP | Notes
C1,C2 | 2 | 1uF |  | CL10A105KA8NNNC | C5673 | Samsung Electro-Mechanics | LCSC
C3 | 1 | 10uF |  | CL10A106KP8NNNC | C19702 | Samsung Electro-Mechanics | LCSC
C9 | 1 | 100nF |  | CL10B104KB8NNNC | C1591 | Samsung Electro-Mechanics | LCSC
D1 | 1 | PESD5V0S1BA |  | PESD5V0S1BA | C5261083 | Nexperia | LCSC
D2 | 1 | USBLC6-2SC6 |  | USBLC6-2SC6 | C2687116 | STMicroelectronics | LCSC
DS1 | 1 | SH1106 OLED |  |  |  |  | LCSC |  |  |  | SH1106 OLED 128x64 I2C module, 4-pin header
F1,F2 | 2 | PTC 1.1A |  | MF-SM013/250-2 | C720650 | Bourns | LCSC
J1 | 1 | TYPE-C-31-M-12 | USB_C_Receptacle_HRO_TYPE-C-31-M-12 | TYPE-C-31-M-12 | C2907321 | HRO | LCSC
J2 | 1 | JST-PH LiPo | JST_PH_B2B-PH-K_1x02_P2.00mm_Vertical | B2B-PH-K-S | C131337 | JST | LCSC
Q1 | 1 | BSS138 | SOT-23 | BSS138 | C112239 | ON Semiconductor | LCSC
R1,R2 | 2 | 5.1k |  | RC0603FR-075K1L | C105580 | Yageo | LCSC
R3 | 1 | 1.1k |  | RC0603FR-071K1L | C137780 | Yageo | LCSC
R4 | 1 | 2.0k |  | RC0603FR-072KL | C105576 | Yageo | LCSC
R5,R6,R7,R8,R9 | 5 | 10k |  | RC0603FR-0710KL | C98220 | Yageo | LCSC
R10,R11 | 2 | 470k |  | RC0603FR-07470KL | C114622 | Yageo | LCSC
R12 | 1 | 100k |  | RC0603FR-07100KL | C14675 | Yageo | LCSC
R_CE,R_CHG,R_FLT | 3 | 10k |  |  |  |  | LCSC
SW1 | 1 | PEC11R |  | PEC11R-4215F-S0024 | C143790 | Bourns | LCSC
SW2 | 1 | BOOT |  | PinHeader_1x02_P2.54mm |  | Generic | LCSC |  |  |  | BOOT header, 2.54mm pin header
TP_RX | 1 | UART_RX |  |  |  |  | LCSC |  |  |  | Test point - no MPN needed, use any 1.3mm test pad
TP_TX | 1 | UART_TX |  |  |  |  | LCSC |  |  |  | Test point - no MPN needed, use any 1.3mm test pad
U1 | 1 | BQ24074RGTR | WQFN-20-1EP_3.5x3.5mm_P0.5mm_EP2.7x2.7mm | BQ24074RGTR | C54313 | Texas Instruments | LCSC | https://www.ti.com/lit/ds/symlink/bq24074.pdf
U2 | 1 | AP2112K-3.3 |  | AP2112K-3.3TRG1 | C23380830 | Diodes Incorporated | LCSC
U3 | 1 | ESP32-C3-MINI-1-N4 |  | ESP32-C3-MINI-1-N4 | C2838502 | Espressif Systems | LCSC

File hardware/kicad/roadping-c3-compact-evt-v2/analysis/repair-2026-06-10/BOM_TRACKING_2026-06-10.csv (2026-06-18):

Reference | Qty | Value | Footprint | MPN | Manufacturer | DigiKey | DK_Stock | Mouser | MO_Stock | LCSC | LC_Stock | Chosen_Distributor | Datasheet | Validated | DNP | Notes
C1,C2 | 2 | 1uF | 0603
C3 | 1 | 10uF | 0603
C4,C5,C9 | 3 | 100nF | 0603
C6,C7 | 2 | 10nF DNP | 0603 |  |  |  |  |  |  |  |  |  |  |  | yes | Optional debounce, DNP by default
C8 | 1 | 100nF DNP | 0603 |  |  |  |  |  |  |  |  |  |  |  | yes | Optional debounce, DNP by default
D1 | 1 | USB_5V_TVS | SOD-323 | PESD5V0S1BA | Nexperia
DS1 | 1 | SH1106_I2C_OLED | OLED_4PIN_VDD_GND_SCK_SDA_2.54MM
F1 | 1 | PTC_USB_5V_1A | 1206 | 1206L110SLWR | Littelfuse
F2 | 1 | PTC_BAT_1A | 1206 | 1206L110SLWR | Littelfuse
J1 | 1 | USB_5V_INPUT | PinHeader_1x02_P2.54mm_Vertical
J2 | 1 | JST_PH_2PIN_LIPO | JST_PH_B2B-PH-K_1x02_P2.00mm_Vertical
J3 | 1 | UART_DEBUG_PROGRAM | TESTPADS_1X06_2.54MM_EVT
R1,R2 | 2 | 4.7k DNP | 0603 |  |  |  |  |  |  |  |  |  |  |  | yes | DNP if SH1106 module has pull-ups
R3,R4,R5 | 3 | 10k | 0603
R6 | 1 | 220k | 0603
R7 | 1 | 100k | 0603
R8 | 1 | 10k DNP | 0603 |  |  |  |  |  |  |  |  |  |  |  | yes | DNP; GPIO9_BOOT_NC must not be held low during reset
SW1 | 1 | PEC11R-4215F-S0024 | XDCR_PEC11R-4215F-S0024
U1 | 1 | TP4056-Module | TP4056-Module
U2 | 1 | AP2112K-3.3 | SOT-23-5 | AP2112K-3.3TRG1 | Diodes Incorporated |  |  |  |  |  |  |  | https://www.diodes.com/datasheet/download/AP2112.pdf
U3 | 1 | ESP32-C3_SUPERMINI_TH | MODULE_ESP32-C3_SUPERMINI_TH

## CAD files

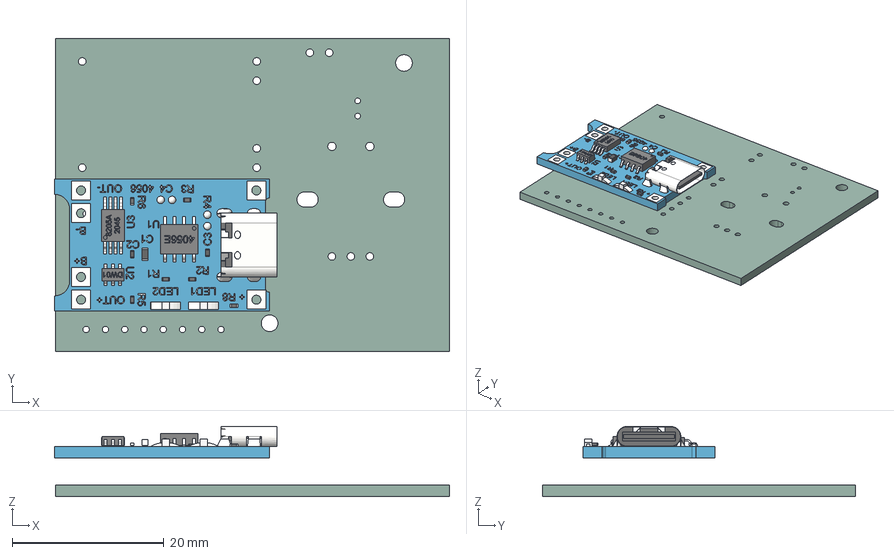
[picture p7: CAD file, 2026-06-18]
hardware/kicad/roadping-c3-compact-evt-v2/analysis/tp4056_3d_model_validation_u1.step
52.0 x 41.2 x 9.23 mm
board
USB_Type_C_Connector
8205A_2045
DW01-P
small1005_smd_resistor x 2
small1005_smd_resistor (1)
small1005_smd_capacitor
smd_capacitor
SOP-8_4056E
solder_dot_round
solder_dot_round (1)
solder_dot_round (2)
solder_dot_round (3)
small1005_smd_capacitor (1)
LED2
LED2 (1)
small1005_smd_resistor (2)
small1005_smd_resistor (4) x 2
soldering
roadping-c3-compact-evt-v2_PCB

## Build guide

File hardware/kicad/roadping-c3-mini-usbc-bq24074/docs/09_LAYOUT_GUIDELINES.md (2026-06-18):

# Layout Guidelines — RoadPing C3 Mini

**Date:** 2026-06-16

---

## 1. General Routing Rules

| Parameter | Value |
|---|---|
| Min trace/space | 0.2mm (0.127mm fab capability) |
| Min via drill | 0.3mm |
| Min via pad | 0.6mm |
| Min annular ring | 0.15mm |
| Clearance copper-edge | 0.5mm |
| Default clearance | 0.2mm |

## 2. Power Routing

| Net | Width | Notes |
|-----|---|---|
| VBUS | 0.5mm | USB-C to BQ24074 IN |
| SYS_RAW | 0.5mm | BQ24074 OUT to AP2112K VIN |
| VBAT | 0.5mm | BQ24074 BAT to JST-PH |
| 3V3 | 0.4mm | Star topology, local branches |

## 3. USB D+/D- (90Ω Differential)

- Width: 0.3mm, spacing: 0.15mm
- F.Cu only, referenced to In1.Cu GND plane
- No vias on pair
- USBLC6 <5mm from connector
- Series resistors (27Ω) on IC side of USBLC6
- Length-matched <2mm

## 4. I2C (SCL/SDA)

- Width: 0.25mm
- Keep short (<100mm total)
- No stubs (daisy-chain preferred)
- Pull-ups near ESP32-C3 side

## 5. Battery ADC (BAT_ADC)

- Guard ring around divider resistors
- No digital traces parallel to ADC trace
- 100nF filter cap close to GPIO0 pin
- Minimal trace length from divider to GPIO0

## 6. Antenna Keepout

- ≥15mm from module antenna edge
- No copper — any layer, any shape
- No components in keepout zone
- DRC keepout rule on F.Cu, In1.Cu, In2.Cu, B.Cu

## 7. BQ24074 Thermal Pad

- WQFN-20 exposed pad (2.7×2.7mm)
- ≥4 thermal vias (0.3mm drill) in pad
- Connect to GND plane on In1.Cu
- Stencil aperture: 60-70% coverage on EP
- Thermal relief on pad vias if hand-solder

## 8. Decoupling

| Cap | Net | Location |
|-----|-----|---|
| 10µF + 100nF | VBUS | Near BQ24074 IN pins |
| 10µF + 100nF | SYS_RAW | Near BQ24074 OUT pin |
| 1µF | SYS_RAW | Near AP2112K VIN |
| 1µF + 10µF | 3V3 | Near AP2112K VOUT |
| 100nF | 3V3 | Near each IC power pin |

## 9. Module GND Stitching

- ≥8 GND vias around ESP32-C3-MINI-1 perimeter
- Direct connection to In1.Cu GND plane
- 0.5mm trace or direct via-to-plane

## 10. Test Points

- 1.3mm round pad, exposed copper, ENIG
- 2.54mm pitch row
- Near board edge for probe access
- GND, 3V3, TX, RX, SCL, BOOT

## 11. Mounting Holes

- 4× M2 NPTH at corners
- 2.2mm drill, 5.0mm copper pad
- 1.4mm clearance from other copper
- GND connection if desired (ferrule optional)

## 12. Fabrication Notes

- 4-layer, 1.6mm, ENIG
- 1oz copper all layers
- FR4 TG 140-170°C
- Impedance coupon for 90Ω diff pair
- Green solder mask, white silkscreen

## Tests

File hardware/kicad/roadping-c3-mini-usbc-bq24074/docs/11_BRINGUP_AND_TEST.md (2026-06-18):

# Bring-Up and Test Plan — RoadPing C3 Mini

**Date:** 2026-06-16

---

## 1. Pre-Power Checks

1. Visual inspection: solder joints, bridges, polarity
2. DMM continuity: VBUS-GND (no short), VBAT-GND (no short), SYS_RAW-GND
3. DMM resistance: 3V3-GND (~kΩ range through LDO+caps)
4. Check J2 polarity: pin 1 = BAT_CONN+, pin 2 = GND
5. Current-limited PSU (100mA limit for first power)

## 2. Power-On Sequence

### Step 1: USB Power Only (no battery)
1. Connect USB-C to current-limited 5V PSU
2. Measure VBUS = 5V±5%
3. Measure SYS_RAW = ~4.4V (BQ24074 OUT from USB)
4. Measure 3V3 = 3.3V±2%
5. Check no excessive current (>50mA idle)

### Step 2: Battery Power Only (no USB)
1. Connect battery simulator (3.7V, current-limited)
2. Measure SYS_RAW = ~3.55V (BAT→OUT)
3. Measure 3V3 = 3.3V±2%
4. Remove simulator, verify SYS_RAW drops to 0V

### Step 3: USB + Battery
1. Connect USB + battery simulator at 3.3V
2. Verify CHG status on GPIO6
3. Measure charge current (~400-500mA input, ~250-350mA to battery)

## 3. USB Enumeration

1. Connect USB-C to PC
2. Check D+/D- differential signal (scope if available)
3. Device should enumerate as USB-SERIAL-JTAG (CDC ACM)
4. Verify `esptool.py chip_id` detects ESP32-C3

## 4. ESP32-C3 Boot

1. Monitor UART TX (GPIO21) — boot log?
2. Verify BOOT button (GPIO9 to GND) enters download mode
3. Flash firmware via `idf.py flash`
4. Verify serial console output via USB CDC-ACM

## 5. Charger Test

| Test | Condition | Expected |
|---|---|---|
| No USB, no battery | GPIO6=HIGH, GPIO7=HIGH | — |
| USB only, no battery | GPIO6=HIGH, GPIO7=HIGH | No battery fault |
| USB + battery (3.3V) | GPIO6=LOW, GPIO7=HIGH | Charging |
| USB + battery (4.2V) | GPIO6=HIGH, GPIO7=HIGH | Charge complete |
| Remove battery | GPIO6=LOW, GPIO7=LOW | Battery absent |

## 6. Gated ADC Test

1. Gate OFF (GPIO1=LOW): read GPIO0 ADC → near 0
2. Gate ON (GPIO1=HIGH): wait 500ms, read ADC → VBAT×0.5
3. Compare with DMM on VBAT

## 7. Display Test

1. I2C scan → 0x3C or 0x3D
2. Send SH1106 init sequence
3. Display test pattern (all pixels on/off/checkerboard)

## 8. Encoder Test

1. Read GPIO2/3 state changes on rotation
2. Read GPIO4 state on press
3. Verify pull-up voltage on all three lines

## 9. Test Points

| Pad | Signal | Measurement |
|-----|---|---|
| TP_GND | GND | 0V |
| TP_3V3 | 3V3 | 3.3V±2% |
| TP_TX | GPIO21 | 3.3V idle, toggle on boot |
| TP_RX | GPIO20 | Input, 3.3V (UART idle) |
| TP_SCL | GPIO10 | 3.3V idle (I2C) |
| TP_BOOT | GPIO9 | 3.3V idle, 0V when BOOT pressed |

## 10. Firmware Flashing

1. Hold BOOT (GPIO9 to GND)
2. Tap EN (power cycle)
3. Release BOOT
4. `idf.py -p /dev/ttyACM0 flash`
5. `idf.py -p /dev/ttyACM0 monitor`

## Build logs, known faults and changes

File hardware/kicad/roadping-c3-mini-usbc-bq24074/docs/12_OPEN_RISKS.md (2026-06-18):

# Open Risks — RoadPing C3 Mini

**Date:** 2026-06-16

---

## R1 — WQFN-20 Reflow (BQ24074RGTR)

**Risk:** 0.5mm pitch WQFN with exposed pad requires reflow assembly. Not hand-solderable without hot-air or hotplate.

**Mitigation:**
- Design stencil with 60-70% aperture on EP
- ≥4 thermal vias in pad
- Pre-heat board to 100°C before reflow
- X-ray inspection after assembly
- Consider pre-tinning EP + hot-air if hand-prototyping

**Owner:** Hardware | **Status:** OPEN

## R2 — USB TVS Clamp Voltage

**Risk:** PESD5V0S1BA clamps at ~9.8V (1A), exceeding BQ24074 abs max 6.5V on IN pin.

**Mitigation:**
- TVS is for ESD (ns pulses), not sustained OVP
- BQ24074 has internal 6.2V OVP for sustained overvoltage
- Accept as-is, document use case
- If issue arises, swap to PESD5V0S1BL (lower clamp) or TPSMA6L

**Owner:** Hardware | **Status:** ACCEPT (documented)

## R3 — BQ24074 ILIM Recalculation

**Risk:** ILIM=10kΩ gives ~100mA input limit, severely restricting charge current when system is active.

**Mitigation:**
- Calculate for 500mA input limit: R_ILIM = 1.0/0.5 × 1000 = 2.0kΩ
- Or 1A input limit: R_ILIM = 1.0kΩ
- Must decide before PCB order (value affects BOM)

**Owner:** Hardware | **Status:** OPEN — needs decision

## R4 — Gated ADC Settling Time

**Risk:** 470k+470k divider + 100nF creates ~106ms RC time constant. Need >500ms settling before ADC read.

**Mitigation:**
- Firmware: GPIO1 HIGH → 500ms delay → ADC read → GPIO1 LOW
- If too slow, reduce filter cap to 10nF (τ=10.6ms)
- Espressif ADC sampling time adjustment for 235kΩ source impedance

**Owner:** Firmware | **Status:** OPEN

## R5 — BSS138 Gate Drive at 3.0V VBAT

**Risk:** BSS138 Vgs(th) is 0.8-1.5V typ, but 3.0V gate drive may not fully enhance the FET when source is at divider bottom (near GND, Vgs ~ 3.3V from GPIO1).

**Mitigation:**
- GPIO1 drives 3.3V, BSS138 source is GND → Vgs = +3.3V (well above Vth)
- Rds(on) at Vgs=3.3V: ~3.5Ω, negligible in 940kΩ divider leg
- No issue: BSS138 confirmed suitable

**Owner:** — | **Status:** ACCEPT

## R6 — ESP32-C3-MINI-1 Footprint Unknown

**Risk:** No verified KiCad footprint for the 42-pin MINI-1-N4 module. Previous design uses Super Mini through-hole footprint — entirely different.

**Mitigation:**
- Create footprint from Espressif datasheet mechanical drawing
- Verify pin 1 location, pitch, row spacing, body dimensions
- Order test coupon before full PCB run

**Owner:** Hardware | **Status:** OPEN — needs footprint creation

## R7 — No NTC on Battery

**Risk:** BQ24074 TS pin fixed with 10k+10k divider. No battery temperature monitoring. Charging continues even if battery overheats.

**Mitigation:**
- BQ24074 die thermal regulation (125°C) provides secondary protection
- 5h safety timer prevents indefinite charging
- Phase 2: add NTC thermistor in battery pack and route to TS pin

**Owner:** Hardware | **Status:** ACCEPT (Phase 1)

## R8 — USB-C Mechanical Retention

**Risk:** TYPE-C-31-M-12 is mid-mount SMT without through-hole posts. Mechanical retention depends entirely on solder.

**Mitigation:**
- Connector has 2 SMT ground posts for additional strength
- If insufficient, switch to TYPE-C-31-M-12B or through-hole post variant
- Apply strain relief on cable side

**Owner:** Mechanical | **Status:** OPEN — verify on first article

## R9 — ADC Calibration Required

**Risk:** ESP32-C3 ADC has ±10% uncalibrated accuracy. Battery percentage will be inaccurate without calibration.

**Mitigation:**
- Phase 1: implement 2-point calibration (3.0V and 4.2V) with bench PSU
- Store calibration factor in NVS
- Phase 2: MAX17048 eliminates ADC entirely

**Owner:** Firmware | **Status:** OPEN (Phase 1) / DEFERRED (Phase 2)

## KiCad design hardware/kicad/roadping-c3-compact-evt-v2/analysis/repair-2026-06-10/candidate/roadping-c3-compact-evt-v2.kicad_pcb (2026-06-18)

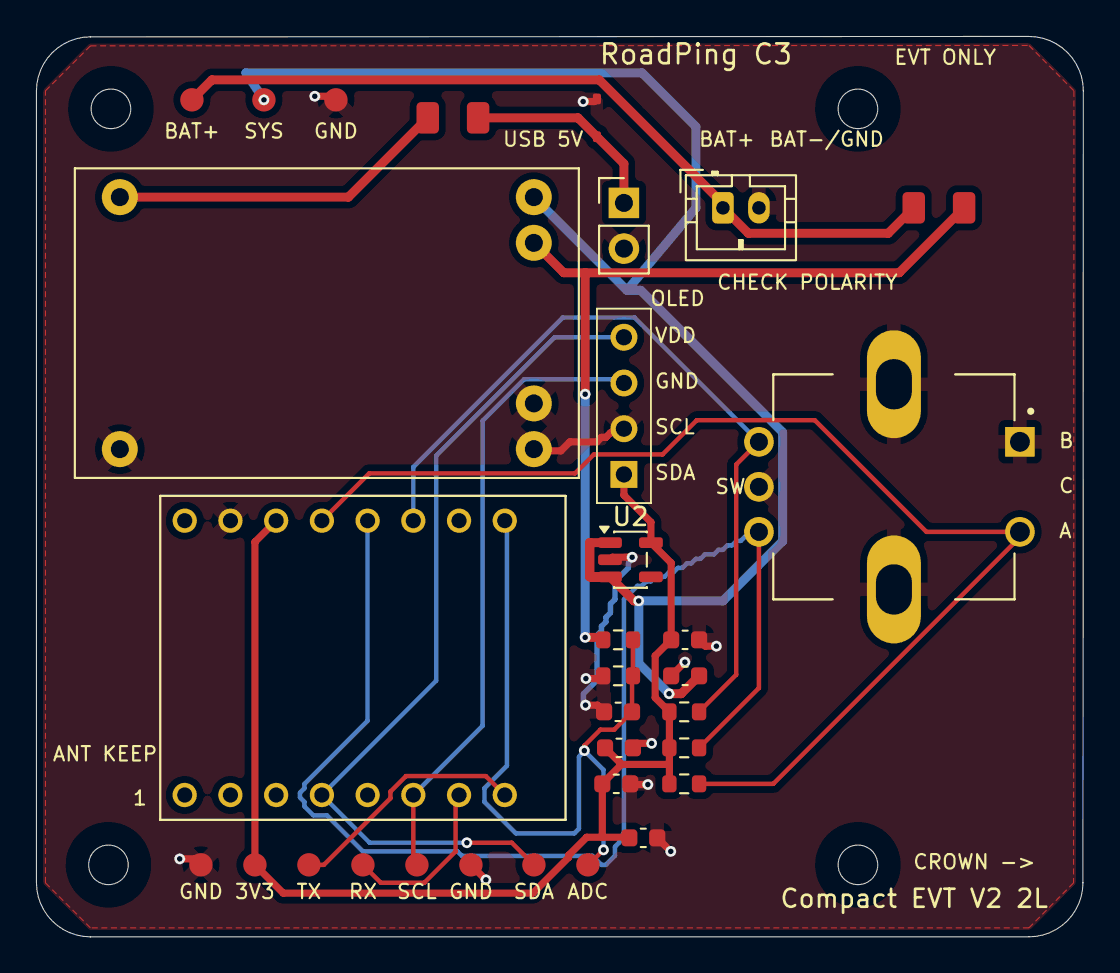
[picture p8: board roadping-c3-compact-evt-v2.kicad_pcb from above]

Board: 2 copper layers, 58.2 x 50.0 mm, 31 parts (0 on the bottom side), 15 nets.

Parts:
C1, C2: 1uF; C_0603_1608Metric
C3: 10uF; C_0603_1608Metric
C4, C5, C9: 100nF; C_0603_1608Metric
D1: USB_5V_TVS; D_SOD-323
DS1: SH1106_I2C_OLED; OLED_4PIN_VDD_GND_SCK_SDA_2.54MM
F1: PTC_USB_5V_1A; Fuse_1206_3216Metric
F2: PTC_BAT_1A; Fuse_1206_3216Metric
J1: USB_5V_INPUT; PinHeader_1x02_P2.54mm_Vertical
J2: JST_PH_2PIN_LIPO; JST_PH_B2B-PH-K_1x02_P2.00mm_Vertical
J3: UART_DEBUG_PROGRAM; TESTPADS_1X06_2.54MM_EVT
MH1, MH2, MH3, MH4: M2_NPTH; MountingHole_M2_NPTH_5mmKeepout
R3, R4, R5: 10k; R_0603_1608Metric
R6: 220k; R_0603_1608Metric
R7: 100k; R_0603_1608Metric
SW1: PEC11R-4215F-S0024; XDCR_PEC11R-4215F-S0024
TP2: BAT_CONN+; TP_Round_1.0mm
TP3: SYS_RAW; TP_Round_1.0mm
TP5: GND; TP_Round_1.0mm
TP8: I2C_SDA; TP_Round_1.0mm
TP13: BAT_ADC; TP_Round_1.0mm
U1: TP4056-Module
U2: AP2112K-3.3; SOT-23-5
U3: ESP32-C3_SUPERMINI_TH; MODULE_ESP32-C3_SUPERMINI_TH

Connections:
/3V3: C2.1, C3.1, C4.1, C5.1, DS1.1 (VDD), J3.2, R3.1, R4.1, R5.1, U2.5 (VOUT), U3.3.3 (3V3)
/BAT_ADC: C9.1, R6.2, R7.1, TP13.1 (1_1), U3.0 (GPIO0)
/BAT_CONN+: F2.1, J2.1 (BAT+), TP2.1 (1_1)
/ENC_A: R3.2, SW1.A, U3.2 (GPIO2)
/ENC_B: R4.2, SW1.B, U3.3 (GPIO3)
/ENC_SW: R5.2, SW1.2 (SW2), U3.4 (GPIO4)
/GND: C1.2, C2.2, C3.2, C4.2, C5.2, C9.2, D1.1, DS1.2 (GND), J1.2, J2.2 (BAT-), J3.1, J3.6, R7.2, SW1.1 (SW1), SW1.C, SW1.S1 (SHIELD1), SW1.S2 (SHIELD2), TP5.1 (1_1), U1.2 (IN-), U1.4 (OUT-), U1.6 (B-), U2.2 (GND), U3.G (GND)
/I2C_SCL: DS1.3 (SCK), J3.5, U3.10 (GPIO10)
/I2C_SDA: DS1.4 (SDA), TP8.1 (1_1), U3.8 (GPIO8)
/SYS_RAW: C1.1, TP3.1 (1_1), U1.3 (OUT+), U2.1 (VIN), U2.3 (EN)
/UART_RX: J3.4, U3.20 (GPIO20)
/UART_TX: J3.3, U3.21 (GPIO21)
/USB_5V: F1.2, U1.1 (IN+)
/USB_5V_IN: D1.2, F1.1, J1.1
/VBAT: F2.2, R6.1, U1.5 (B+)

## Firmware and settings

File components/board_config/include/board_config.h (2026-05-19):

#pragma once

#include "driver/gpio.h"
#include "driver/i2c_types.h"
#include "hal/adc_types.h"

#ifdef __cplusplus
extern "C" {
#endif

#define BOARD_DEVICE_NAME                    "C3-ANCS"

#define BOARD_I2C_PORT                       I2C_NUM_0
#define BOARD_I2C_SDA_GPIO                   GPIO_NUM_6
#define BOARD_I2C_SCL_GPIO                   GPIO_NUM_7
#define BOARD_I2C_CLOCK_HZ                   400000
#define BOARD_I2C_GLITCH_IGNORE_CNT          7

#define BOARD_SH1106_I2C_ADDRESS             0x3C
#define BOARD_SH1106_RESET_GPIO              ((gpio_num_t)-1)
#define BOARD_SH1106_WIDTH                   128
#define BOARD_SH1106_HEIGHT                  64
#define BOARD_SH1106_RAM_WIDTH               132
#define BOARD_SH1106_COLUMN_OFFSET           2
#define BOARD_SH1106_CONTRAST                0x80
#define BOARD_SH1106_MIRROR_X                1
#define BOARD_SH1106_MIRROR_Y                1

#define BOARD_NOTIFICATION_QUEUE_MAX         30
#define BOARD_ANCS_ATTR_QUEUE_MAX            10
#define BOARD_APP_EVENT_QUEUE_LEN            64
#define BOARD_APP_EVENT_SEND_WAIT_MS         10
#define BOARD_APP_FILTER_OVERLAY_MS          800
#define BOARD_APP_REBOOT_DELAY_MS            800
#define BOARD_ANCS_APP_ID_MAX_LEN            40
#define BOARD_ANCS_TITLE_MAX_LEN             64
#define BOARD_ANCS_MESSAGE_MAX_LEN           160
#define BOARD_NAV_SOURCE_MAX_LEN             32
#define BOARD_NAV_DISTANCE_MAX_LEN           24
#define BOARD_NAV_ETA_MAX_LEN                24
#define BOARD_NAV_PAYLOAD_MAX_LEN            384
#define BOARD_ANCS_DS_BUFFER_SIZE            384
#define BOARD_ANCS_PREEXISTING_ENRICH_MAX    4
#define BOARD_NOTIFICATION_APP_CONFIG_MAX    32
#define BOARD_NOTIFICATION_APP_PAGE_SIZE     4
#define BOARD_ANCS_ATTR_REQUEST_TIMEOUT_MS   2500
#define BOARD_ANCS_ATTR_RETRY_DELAY_MS       500
#define BOARD_ANCS_ATTR_MAX_RETRIES          2
#define BOARD_ANCS_DISCOVERY_DELAY_MS        3000
#define BOARD_ANCS_DISCOVERY_FIRST_BOND_MS   5000
#define BOARD_ANCS_DISCOVERY_RETRY_MS        3000
#define BOARD_ANCS_DISCOVERY_MAX_RETRIES     5
#define BOARD_BLE_DIRECTED_ADV_MS            5000
#define BOARD_BLE_RECONNECT_DELAY_MS         3000
#define BOARD_BLE_BOND_RECOVERY_ON_SEC_FAIL  1

#define BOARD_BUTTON_A_GPIO_PRIMARY          GPIO_NUM_3
#define BOARD_BUTTON_A_GPIO_SECONDARY        ((gpio_num_t)-1)
#define BOARD_BUTTON_B_GPIO_PRIMARY          GPIO_NUM_4
#define BOARD_BUTTON_B_GPIO_SECONDARY        ((gpio_num_t)-1)
#define BOARD_BUTTON_POLL_MS                 20
#define BOARD_BUTTON_DEBOUNCE_MS             40
#define BOARD_BUTTON_LONG_PRESS_MS           800
#define BOARD_BUTTON_AB_LONG_PRESS_MS        3000

#define BOARD_DISPLAY_FB_SIZE                (BOARD_SH1106_WIDTH * BOARD_SH1106_HEIGHT / 8)
#define BOARD_DISPLAY_AUTO_OFF_MS            15000

/* Battery ADC: voltage divider 2:1 (R_top:R_bot) → V_adc = V_bat / 3.
 * Reading 1400mV → 4.2V battery. ADC_ATTEN_DB_12 covers 0..3.1V. */
#define BOARD_BATTERY_ADC_GPIO               GPIO_NUM_1
#define BOARD_BATTERY_ADC_CHANNEL            ADC_CHANNEL_1
#define BOARD_BATTERY_ADC_UNIT               ADC_UNIT_1
#define BOARD_BATTERY_DIVIDER_NUM            3
#define BOARD_BATTERY_DIVIDER_DEN            1
#define BOARD_BATTERY_SAMPLE_COUNT           8

/* TP4056 STAT pins (open-drain, internal pull-up enabled).
 * CHRG=L → charging, STDBY=L → charge complete.
 * Both GPIO5 and GPIO10 are non-strapping on ESP32-C3 — boot is unaffected. */
#define BOARD_TP4056_CHRG_GPIO               GPIO_NUM_5
#define BOARD_TP4056_STDBY_GPIO              GPIO_NUM_10

#define BOARD_POWER_SAMPLE_MS                10000
#define BOARD_POWER_BATTERY_FULL_MV          4200
#define BOARD_POWER_BATTERY_EMPTY_MV         3300
#define BOARD_POWER_BATTERY_LOW_PCT          15
#define BOARD_POWER_BATTERY_CRITICAL_PCT     5

#define BOARD_TAG_STORAGE                    "storage_mgr"
#define BOARD_TAG_DISPLAY                    "display_mgr"
#define BOARD_TAG_TEXT                       "text_rndr"
#define BOARD_TAG_SH1106                     "sh1106"
#define BOARD_TAG_BLE                        "ble_mgr"
#define BOARD_TAG_ANCS                       "ancs_cli"
#define BOARD_TAG_ANCS_PARSER                "ancs_parse"
#define BOARD_TAG_STORE                      "notif_store"
#define BOARD_TAG_BUTTON                     "button_mgr"
#define BOARD_TAG_POWER                      "power_mgr"
#define BOARD_TAG_APP                        "app"

#ifdef __cplusplus
}
#endif

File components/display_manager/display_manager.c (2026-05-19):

#include "display_manager.h"

#include <ctype.h>
#include <stdlib.h>
#include <string.h>
#include "board_config.h"
#include "driver/i2c_master.h"
#include "esp_check.h"
#include "esp_lcd_io_i2c.h"
#include "esp_lcd_panel_io.h"
#include "esp_lcd_panel_ops.h"
#include "esp_log.h"
#include "freertos/FreeRTOS.h"
#include "freertos/semphr.h"
#include "sh1106_panel.h"
#include "text_renderer.h"

struct display_manager {
    i2c_master_bus_handle_t i2c_bus;
    esp_lcd_panel_io_handle_t io_handle;
    esp_lcd_panel_handle_t panel_handle;
    uint8_t framebuffer[BOARD_DISPLAY_FB_SIZE];
    SemaphoreHandle_t lock;
};

static const char *TAG = BOARD_TAG_DISPLAY;
static const uint16_t s_probe_addresses[] = {
    BOARD_SH1106_I2C_ADDRESS,
    0x3C,
    0x3D,
};

typedef struct {
    const char *bundle_id;
    const char *display_name;
} display_app_name_map_t;

static const display_app_name_map_t s_app_name_map[] = {
    { "com.apple.mobilephone", "Phone" },
    { "com.apple.MobileSMS", "Messages" },
    { "com.apple.mobilemail", "Mail" },
    { "com.apple.Preferences", "Settings" },
    { "com.apple.Maps", "Maps" },
    { "com.google.Maps", "Google Maps" },
    { "com.apple.calculator", "Calculator" },
    { "com.apple.weather", "Weather" },
    { "com.google.Gmail", "Gmail" },
    { "com.facebook.Messenger", "Messenger" },
    { "net.whatsapp.WhatsApp", "WhatsApp" },
    { "org.telegram.messenger", "Telegram" },
    { "org.whispersystems.signal", "Signal" },
    { "com.waze.iphone", "Waze" },
};

static esp_err_t display_flush_locked(display_handle_t handle)
{
    return esp_lcd_panel_draw_bitmap(handle->panel_handle, 0, 0,
                                     BOARD_SH1106_WIDTH, BOARD_SH1106_HEIGHT,
                                     handle->framebuffer);
}

static uint16_t display_select_i2c_address(i2c_master_bus_handle_t bus)
{
    uint16_t detected_address = BOARD_SH1106_I2C_ADDRESS;

    for (size_t i = 0; i < sizeof(s_probe_addresses) / sizeof(s_probe_addresses[0]); ++i) {
        uint16_t address = s_probe_addresses[i];

        if (i > 0) {
            bool duplicate = false;

            for (size_t j = 0; j < i; ++j) {
                if (s_probe_addresses[j] == address) {
                    duplicate = true;
                    break;
                }
            }
            if (duplicate) {
                continue;
            }
        }

        if (i2c_master_probe(bus, address, 50) == ESP_OK) {
            ESP_LOGI(TAG, "I2C device acknowledged at 0x%02X", address);
            detected_address = address;
            if (address != BOARD_SH1106_I2C_ADDRESS) {
                ESP_LOGW(TAG, "configured SH1106 address 0x%02X not found, using 0x%02X instead",
                         BOARD_SH1106_I2C_ADDRESS, address);
            }
            return detected_address;
        }

        ESP_LOGW(TAG, "no I2C ACK at 0x%02X", address);
    }

    ESP_LOGW(TAG, "no SH1106 detected on I2C, keeping configured address 0x%02X",
             BOARD_SH1106_I2C_ADDRESS);
    return detected_address;
}

static const char *display_safe_text(const char *text)
{
    return (text != NULL && text[0] != '\0') ? text : "";
}

static size_t display_utf8_sequence_len(uint8_t lead)
{
    if ((lead & 0x80U) == 0U) {
        return 1;
    }
    if ((lead & 0xE0U) == 0xC0U) {
        return 2;
    }
    if ((lead & 0xF0U) == 0xE0U) {
        return 3;
    }
    if ((lead & 0xF8U) == 0xF0U) {
        return 4;
    }
    return 1;
}

static bool display_decode_utf8_char(const uint8_t *in, size_t *consumed, uint32_t *codepoint)
{
    size_t len;

    if (in == NULL || consumed == NULL || codepoint == NULL || in[0] == 0U) {
        return false;
    }

    len = display_utf8_sequence_len(in[0]);
    *consumed = len;

    switch (len) {
    case 1:
        *codepoint = in[0];
        return true;
    case 2:
        if ((in[1] & 0xC0U) != 0x80U) {
            *codepoint = in[0];
            *consumed = 1;
            return false;
        }
        *codepoint = ((uint32_t)(in[0] & 0x1FU) << 6) |
                     ((uint32_t)(in[1] & 0x3FU));
        return true;
    case 3:
        if ((in[1] & 0xC0U) != 0x80U || (in[2] & 0xC0U) != 0x80U) {
            *codepoint = in[0];
            *consumed = 1;
            return false;
        }
        *codepoint = ((uint32_t)(in[0] & 0x0FU) << 12) |
                     ((uint32_t)(in[1] & 0x3FU) << 6) |
                     ((uint32_t)(in[2] & 0x3FU));
        return true;
    case 4:
        if ((in[1] & 0xC0U) != 0x80U || (in[2] & 0xC0U) != 0x80U || (in[3] & 0xC0U) != 0x80U) {
            *codepoint = in[0];
            *consumed = 1;
            return false;
        }
        *codepoint = ((uint32_t)(in[0] & 0x07U) << 18) |
                     ((uint32_t)(in[1] & 0x3FU) << 12) |
                     ((uint32_t)(in[2] & 0x3FU) << 6) |
                     ((uint32_t)(in[3] & 0x3FU));
        return true;
    default:
        *codepoint = in[0];
        *consumed = 1;
        return false;
    }
}

static void display_append_char(char *out, size_t out_size, size_t *offset, char c)
{
    if (out == NULL || offset == NULL || out_size == 0 || *offset >= (out_size - 1U)) {
        return;
    }
    out[(*offset)++] = c;
    out[*offset] = '\0';
}

static void display_append_text(char *out, size_t out_size, size_t *offset, const char *text)
{
    if (text == NULL) {
        return;
    }

    while (*text != '\0' && *offset < (out_size - 1U)) {
        out[(*offset)++] = *text++;
    }
    out[*offset] = '\0';
}

static void display_append_bytes(char *out, size_t out_size, size_t *offset, const uint8_t *bytes, size_t len)
{
    if (out == NULL || offset == NULL || bytes == NULL || out_size == 0) {
        return;
    }

    while (len > 0U && *offset < (out_size - 1U)) {
        out[(*offset)++] = (char)*bytes++;
        len--;
    }
    out[*offset] = '\0';
}
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

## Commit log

2026-04-11 Add app skeleton and core board components
2026-05-19 Fix ANCS reconnect notification handling
    [board_config.h]
2026-06-18 Add BQ24074 hardware plan
    [bom.csv, order_lcsc.csv, roadping-c3-mini-usbc-bq24074.kicad_pcb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]
2026-06-18 Add compact EVT analysis artifacts
    [BOM_TRACKING_2026-06-10.csv, compact-iter1-placed-routes-kept.kicad_pcb, compact-iter1-placement.kicad_pcb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]

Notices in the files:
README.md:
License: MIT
